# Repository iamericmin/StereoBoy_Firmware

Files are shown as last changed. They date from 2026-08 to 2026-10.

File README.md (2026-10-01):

# StereoBoy Firmware

Open-source firmware & hardware files for StereoBoy, the portable & modular stereo system!

The firmware project is organized as a Pico-SDK project that you can import directly into VSCode with Raspberry Pi's official Raspberry Pi Pico extension. You might need to git clone the [no-OS-FatFS-SD-SDIO-SPI-RPi-Pico repository](https://hackaday.io/project/205771-stereoboy).

The KiCad_files contains the full KiCad project should you want to produce your own PCBs. Make sure to order them in 1mm thickness, or else they won't fit into a GameBoy Pocket shell properly!!!

## What is this?

### FULL DISCLAIMER: I use AI-generated code for parts of this project! AI was used mainly for debugging and quick prototyping.



StereoBoy is a portable audio player I designed to be fit inside an original GameBoy Pocket shell. Read more about it here: [Hackaday Project Page](https://hackaday.io/project/205771-stereoboy)

**My main focus on the software side is providing a no-BS listening experience. For me, this implies a few things:**

 - Instant boot-up time
 - Intuitive UI that should ideally be easy enough to use without a manual
 - Simple, snappy UI that provides quick navigation between tracks, albums, artists, etc.
 - Easy to load music, with no software to manage file transfer
 - Plus the usual features such as an album art, equalizer, fast forward/rewind, etc.

So far, I've achieved sub-1s boot time that instantly provides a simple, iPod-like menu for albums, artists, and tracks as soon as you turn the device on, with a snappy interface that allows navigating through thousands of tracks with zero noticeable lag.

Music is loaded simply by dragging and dropping audio files on a micro-SD card, although a python script needs to be run to update the system cache with new track metadata. The script takes about 1.5 minutes to parse through a library of a little over 2000 songs. Thanks to the pre-generated metadata cache files, StereoBoy can instantly load fully sorted menus and crisp album artwork pretty much instantaneously.

Currently I have a very rudimentary equalizer going as well as buttery smooth fast forward/rewind. MP3s are the only supported file format, but I plan on adding FLAC support too.

**However, I also wanted to add some of my own personality to give the firmware some charm. Examples include:**

 - warp effect when pausing/resuming to simulate an analog tape reel. It's my favorite part of the entire project and never ever gets annoying.
 - Oscilloscope visualizer that displays super-high FPS waveforms of left and right channel audio
 - Audio plays at slightly lower speed and pitch on low battery to simulate a dying walkman (work in progress!)

## Let's get technical
### Here's a block diagram of the firmware architecture:

asdf

The firmware runs in a producer-consumer architecture, with Core 0 acting as the producer and Core 1 as the consumer. Core 0 mainly handles low-level peripherals and filesystem IO, such as opening/reading files and parsing track metadata. Core 1 mainly handles graphics and UI, reading data generated by Core 0 and rendering the appropriate visualizer/interface on the display and LEDs.

Both cores run their own superloop with very few interrupt-based routines. The firmware originally started out as a quick prototyping exercise for some core components, but eventually snowballed into what it is right now, and frankly I think it works alright for the task at hand. The current firmware architecture made it pretty easy to add features and modify existing components.

### Now here's a block diagram of the hardware architecture:



While the star of the show is an RP2350B microcontroller, it's actually a VS1063 audio codec that does the heavy lifting of all things related to audio. The RP2350's two cores handle user interface logic, graphics, and filesystem operations, while the codec crunches through audio data and provides the RP2350 with analog audio data, along with other useful tidbits of info such as playback timestamp or sampling frequency.

I2S output from the VS1063 is sent to a TLV320DAC3100, which is an integrated I2S DAC and headphone/speaker amp. It also controls the final output volume. The display is a 240x240 1.54" TFT LCD, and there is twin-bar VU meter for some extra flair. Currently it's only used as a visualizer but I plan on implementing more features into it, such as a battery level indicator. There is an 8KB FRAM chip to store last played track data plus some settings, and an 8-bit shift register takes care of all eight buttons to output to a single GPIO pin on the RP2350.

The power supply is a "double decker" structure where two PCBs are stacked on top of each other, with the top half containing the priority mux and 5V boost, while the bottom half contains the 1.8V and 3.3V buck regulators.

## The Future
### What do I have planned for the future?

 - 5-band graphic equalizer
 - Queue/play next
 - High-FPS FFT visualizer
 - Playlists
 - FLAC support
 - Last played song and timestamp available on boot-up
 - Settings to choose interface options and colors
 - Extras, like a timer/stopwatch/calendar
 - Games, like music quiz
 - More intuitive UI, some parts are a little clunky to use

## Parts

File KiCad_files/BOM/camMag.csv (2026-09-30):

Id | Designator | Footprint | Quantity | Designation | Supplier and ref
1 | J1 | GameBoy_GamePak_CGB-002_P1.50mm_Edge | 1 | GameBoy_GamePak_CGB-002
2 | C12,C16,C22,C18,C9,C14 | C_0402_1005Metric_Pad0.74x0.62mm_HandSolder | 6 | 10n
3 | C3,C15,C5,C13,C17,C4,C23 | C_0402_1005Metric_Pad0.74x0.62mm_HandSolder | 7 | 0.1u
4 | R5 | R_0402_1005Metric_Pad0.72x0.64mm_HandSolder | 1 | 1M
5 | J6 | microSD_External_Pin | 1 | microSD
6 | R4 | R_0402_1005Metric_Pad0.72x0.64mm_HandSolder | 1 | 1.69k
7 | FB1 | L_0603_1608Metric_Pad1.05x0.95mm_HandSolder | 1 | FerriteBead_Small
8 | C2,C1 | C_1206_3216Metric | 2 | 0.1uF
9 | D1 | LED_0603_1608Metric_Green | 1 | Green
10 | C21,C20 | C_0402_1005Metric_Pad0.74x0.62mm_HandSolder | 2 | 47p
11 | U2 | CP_32_12_ADI | 1 | ADV7180BCP32Z
12 | C19 | C_0402_1005Metric_Pad0.74x0.62mm_HandSolder | 1 | 82n
13 | U4 | SOT-23-5 | 1 | AP2112K-1.8
14 | C10,C11 | C_0603_1608Metric | 2 | 0.1u
15 | J2 | JST_ZH_B4B-ZR_1x04_P1.50mm_Vertical | 1 | Conn_01x04_Pin
16 | R6 | R_0603_1608Metric | 1 | 4k
17 | R3 | R_0402_1005Metric_Pad0.72x0.64mm_HandSolder | 1 | 36
18 | R1 | R_0603_1608Metric | 1 | 470
19 | Y1 | Crystal_SMD_Abracon_ABM8AIG-4Pin_3.2x2.5mm | 1 | ABM8-25.000MHZ-B2-T
20 | JP1 | R_0603_1608Metric | 1 | Jumper_2_Open
21 | R7 | R_0603_1608Metric | 1 | 470
22 | D2 | LED_0603_1608Metric | 1 | Blue
23 | C8 | C_0603_1608Metric_Pad1.08x0.95mm_HandSolder | 1 | 0.1u
24 | C6 | C_0603_1608Metric | 1 | 0.1uF
25 | R2 | R_0402_1005Metric_Pad0.72x0.64mm_HandSolder | 1 | 39
26 | U1 | SOIC-8_5.3x5.3mm_P1.27mm | 1 | W25Q16JVSS

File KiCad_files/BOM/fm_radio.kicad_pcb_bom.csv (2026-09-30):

Designator | Quantity | Value | Footprint | Package | MPN | DNP | Mount_Type | Description | PROD_ID | Voltage | Tolerance | Sim.Pins | MANUFACTURER | PART_REV | STANDARD
C1, C8 | 2 | 0.1uF | C_1206_3216Metric_Pad1.33x1.80mm_HandSolder |  |  |  | smt | Unpolarized capacitor | CAP-25565 | 16V | 10%
C11, C12 | 2 | 0.47 uF | C_0402_1005Metric_Pad0.74x0.62mm_HandSolder |  |  |  | smt | Unpolarized capacitor
C13 | 1 | 1 uF | C_0402_1005Metric_Pad0.74x0.62mm_HandSolder |  |  |  | smt | Unpolarized capacitor
C14, C17 | 2 | 100 pF | C_0402_1005Metric_Pad0.74x0.62mm_HandSolder |  |  |  | smt | Unpolarized capacitor
C15, C16 | 2 | 125 uF | C_0402_1005Metric_Pad0.74x0.62mm_HandSolder |  |  |  | smt | Unpolarized capacitor
C18 | 1 | 100pF | C_0402_1005Metric_Pad0.74x0.62mm_HandSolder |  |  |  | smt | Unpolarized capacitor
C2 | 1 | 4.7 uF | C_0402_1005Metric_Pad0.74x0.62mm_HandSolder |  |  |  | smt | Unpolarized capacitor
C3 | 1 | 1 nF | C_0402_1005Metric_Pad0.74x0.62mm_HandSolder |  |  |  | smt | Unpolarized capacitor
C4, C9 | 2 | 100 nF | C_0402_1005Metric_Pad0.74x0.62mm_HandSolder |  |  |  | smt | Unpolarized capacitor
C5 | 1 | 22 nF | C_0402_1005Metric_Pad0.74x0.62mm_HandSolder |  |  |  | smt | Unpolarized capacitor
C6 | 1 | 0.1uF | C_0402_1005Metric_Pad0.74x0.62mm_HandSolder |  |  |  | smt | Unpolarized capacitor | CAP-00810 | 25V | 20%
C7 | 1 | 0.1uF | C_0603_1608Metric |  |  |  | smt | Unpolarized capacitor | CAP-00810 | 25V | 20%
D1, D2, D3 | 3 | TPD1E01B04DPYR | DIO_TPD1E05U06DPYR |  |  |  | smt
D4 | 1 | LED | LED_0603_1608Metric_Pad1.05x0.95mm_HandSolder |  |  |  | smt | Light emitting diode |  |  |  | 1=K 2=A
FB1, FB2 | 2 | FerriteBead_Small | BEADC1608X95N |  |  |  | smt | Ferrite bead, small symbol
J1 | 1 | GameBoy_GamePak_CGB-002 | GameBoy_GamePak_CGB-002_P1.50mm_Edge |  |  |  | tht
J2 | 1 | SJ-43514 | SJ_43514 |  |  |  | tht |  |  |  |  |  | CUI INC | 1.04 | MANUFACTURER RECOMMENDATIONS
J6 | 1 | microSD | microSD_External_Pin |  |  |  | smt | Micro SD socket External Pin | CONN-16110
L1 | 1 | 270 nH | L_0402_1005Metric_Pad0.77x0.64mm_HandSolder |  |  |  | smt | Inductor
R1 | 1 | 1k | R_0603_1608Metric |  |  |  | smt | Resistor | RES-07869
R10, R4, R5, R6, R7 | 5 | 20k | R_0603_1608Metric |  |  |  | smt | Resistor | RES-07869
R11 | 1 | 600 | R_0603_1608Metric |  |  |  | smt | Resistor | RES-07869
R12, R13 | 2 | 2k | R_0603_1608Metric |  |  |  | smt | Resistor | RES-07869
R2, R3 | 2 | 4.7k | R_0603_1608Metric |  |  |  | smt | Resistor | RES-07869
R8, R9 | 2 | 100k | R_0603_1608Metric |  |  |  | smt | Resistor | RES-07869
U1 | 1 | W25Q16JVSS | SOIC-8_5.3x5.3mm_P1.27mm |  |  |  | smt | 16Mbit / 2MiB Serial Flash Memory, Standard/Dual/Quad SPI, 2.7-3.6V, SOIC-8 (208 mil)
U2 | 1 | SI4705-D60-GU | SOP64P600X175-24N |  |  |  | smt
U4 | 1 | LM4810 | TSSOP-8_3x3mm_P0.65mm |  |  |  | smt | Boomer Dual 105mW Headphone Amplifier with Active-High Shutdown Mode, VSSOP-8
Y2 | 1 | SIT1533AI-H4-DCC-32.768E | XTAL4_SiT1533_SIT |  |  |  | smt | SiTime Low Power Mems programmable oscillator, 1MHz to 110MHz, PQFN-4, 2.5x2.0mm (with NC pin)

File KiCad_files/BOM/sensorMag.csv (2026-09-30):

Id | Designator | Footprint | Quantity | Designation | Supplier and ref
1 | J1 | GameBoy_GamePak_CGB-002_P1.50mm_Edge | 1 | GameBoy_GamePak_CGB-002
2 | BT1 | BAT_BAT-HLD-012-SMT | 1 | BAT-HLD-012-SMT
3 | R4 | R_0603_1608Metric_Pad0.98x0.95mm_HandSolder | 1 | 1000
4 | J6 | microSD_External_Pin | 1 | microSD
5 | U3 | Bosch_LGA-8_2.5x2.5mm_P0.65mm_ClockwisePinNumbering | 1 | BME280
6 | R7 | R_0603_1608Metric | 1 | 4.7k
7 | C10 | C_0603_1608Metric_Pad1.08x0.95mm_HandSolder | 1 | 1u
8 | R3 | R_0603_1608Metric | 1 | 10k
9 | C4,C3,C5,C8 | C_0603_1608Metric | 4 | 100n
10 | C2,C1 | C_1206_3216Metric | 2 | 0.1uF
11 | D1 | LED_0603_1608Metric_Green | 1 | Green
12 | C11,C9 | C_0603_1608Metric_Pad1.08x0.95mm_HandSolder | 2 | 0.1u
13 | R5 | R_0603_1608Metric_Pad0.98x0.95mm_HandSolder | 1 | 4.7k
14 | R2,R6 | R_0603_1608Metric | 2 | 0
15 | U6 | OPTO-SMD_LITEON_LTR-381RGB-01 | 1 | ColorSensor
16 | R1 | R_0603_1608Metric | 1 | 470
17 | U4 | SOIC-14_L10.1-W5.0-P1.27-LS7.4-BL | 1 | RealTimeClock
18 | U2 | XDCR_LSM6DSO32TR | 1 | LSM6DSO32TR
19 | D2 | SOT-23 | 1 | BAT54C
20 | C6 | C_0603_1608Metric | 1 | 0.1uF
21 | U1 | SOIC-8_5.3x5.3mm_P1.27mm | 1 | W25Q16JVSS

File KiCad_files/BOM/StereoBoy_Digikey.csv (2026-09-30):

Index | Quantity | Part Number | Manufacturer Part Number | Description | Customer Reference | Available | Backorder | Unit Price | Extended Price USD
1 | 5 | 2648-SC1510-A4CT-ND | SC1510-A4 | RP2350B / 7" REEL - 500PCS |  | 5 | 0 | 1.00000 | 5.00
2 | 5 | 535-AMPLH7020S-6R8MTCT-ND | AMPLH7020S-6R8MT | FIXED IND 6.8UH 5.3A 64 MOHM SMD |  | 5 | 0 | 0.82000 | 4.10
3 | 5 | 516-4291-1-ND | ASMB-LTD2-0A333 | LED RGB DIFFUSED 4PLCC SMD |  | 5 | 0 | 0.58000 | 2.90
4 | 2 | 296-27216-1-ND | TLV320DAC3100IRHBR | IC DAC 24BIT 192K 32VQFN |  | 2 | 0 | 2.30000 | 4.60
5 | 1 | 4809-RK10J11R0A0LCT-ND | RK10J11R0A0L | THUMBWHEEL POT 10KOHM 0.03W TOP |  | 1 | 0 | 2.87000 | 2.87
6 | 1 | APX803S-31SA-7DICT-ND | APX803S-31SA-7 | IC SUPERVISOR 1 CHANNEL SOT23 |  | 1 | 0 | 0.24000 | 0.24
7 | 1 | BSS138CT-ND | BSS138 | MOSFET N-CH 50V 220MA SOT23-3 |  | 1 | 0 | 0.28000 | 0.28
8 | 1 | 497-11883-1-ND | USBLC6-4SC6Y | TVS DIODE 5.25VWM 17VC SOT23-6 |  | 1 | 0 | 0.32000 | 0.32
9 | 4 | 2073-USB4105-GF-A-120CT-ND | USB4105-GF-A-120 | CONN RCP USB2.0 TYP C 16P SMD RA |  | 4 | 0 | 0.78000 | 3.12
10 | 1 | DMG2301L-7DICT-ND | DMG2301L-7 | MOSFET P-CH 20V 3A SOT23 |  | 1 | 0 | 0.26000 | 0.26
11 | 1 | 490-9647-1-ND | PKMCS0909E4000-R1 | BUZZER PIEZO 9X9MM SMD |  | 1 | 0 | 0.92000 | 0.92
12 | 5 | 535-AOTA-B201610S3R3-101-TCT-ND | AOTA-B201610S3R3-101-T | FIXED IND 3.3UH 2.1A 140 MOHM |  | 5 | 0 | 0.21000 | 1.05
13 | 1 | FDN306PCT-ND | FDN306P | MOSFET P-CH 12V 2.6A SUPERSOT3 |  | 1 | 0 | 0.70000 | 0.70
14 | 2 | 296-23151-1-ND | SN74HC165DBR | IC SHIFT REGTR COMP 8BIT 16-SSOP |  | 2 | 0 | 0.44000 | 0.88
15 | 1 | 448-FM24C64B-GTRCT-ND | FM24C64B-GTR | IC FRAM 64KBIT I2C 1MHZ 8SOIC |  | 1 | 0 | 3.17000 | 3.17
16 | 10 | W25Q32JWSSIQ-ND | W25Q32JWSSIQ | IC FLASH 32MBIT SPI/QUAD 8SOIC |  | 10 | 0 | 1.02900 | 10.29
17 | 2 | 296-15240-1-ND | TPS61092RSAR | IC REG BOOST 5V 2A 16QFN |  | 2 | 0 | 2.71000 | 5.42
18 | 2 | 296-47360-1-ND | TLV62569DBVR | IC REG BUCK ADJ 2A SOT23-5 |  | 2 | 0 | 0.25000 | 0.50
19 | 10 | 535-AMELA3012S-2R2MTCT-ND | AMELA3012S-2R2MT | FIXED IND 2.2UH 3.3A 74 MOHM SMD |  | 10 | 0 | 0.77300 | 7.73
20 | 2 | 535-ABM8-272-T3CT-ND | ABM8-272-T3 | CRYSTAL 12.0000MHZ 10PF SMD |  | 2 | 0 | 0.54000 | 1.08
21 | 1 | 296-48721-1-ND | TPD1E01B04DPYR | TVS DIODE 3.6VWM 15VC 2X1SON |  | 1 | 0 | 0.39000 | 0.39
22 | 1 | 1473-1239-1-ND | SIT1533AI-H4-DCC-32.768E | MEMS OSC XO 32.7680KHZ LVCMOS |  | 1 | 0 | 1.33000 | 1.33
23 | 1 | 296-10846-1-ND | TPA6111A2DR | IC AMP CLASS AB STER 150MW 8SOIC |  | 1 | 0 | 1.13000 | 1.13
24 | 2 | CP-43514-ND | SJ-43514 | CONN JACK 4COND 3.5MM R/A |  | 2 | 0 | 1.20000 | 2.40
25 | 1 | 1N4148WTCT-ND | 1N4148WT | DIODE STANDARD 75V 200MA SOD523F |  | 1 | 0 | 0.11000 | 0.11
26 | 2 | 497-LSM6DSO32CT-ND | LSM6DSO32TR | INEMO INERTIAL MODULE: 3D ACCELE |  | 2 | 0 | 3.50000 | 7.00
27 | 2 | 828-1063-1-ND | BME280 | SENSOR PRESSURE HUMIDITY TEMP |  | 2 | 0 | 4.03000 | 8.06
28 | 2 | 568-5306-1-ND | PCF8523T/1,118 | IC RTC CLOCK/CALENDAR I2C 8SO |  | 2 | 0 | 1.35000 | 2.70
29 | 2 | AP2112K-1.8TRG1DICT-ND | AP2112K-1.8TRG1 | IC REG LINEAR 1.8V 600MA SOT-25 |  | 2 | 0 | 0.22000 | 0.44
30 | 2 | 535-9143-1-ND | ABM8-28.63636MHZ-B2-T | CRYSTAL 28.63636MHZ 18PF SMD |  | 2 | 0 | 0.43000 | 0.86
31 | 1 | 1528-2645-ND | 1681 | VS1053B MP3/WAV/OGG/MIDI PLAYER |  | 1 | 0 | 12.50000 | 12.50
32 | 10 | 493-3821-1-ND | RSL0J221MCN1GB | CAP ALUM POLY 220UF 20% 6.3V SMD |  | 10 | 0 | 0.73300 | 7.33
33 | 5 | 478-KC2016Z12.2880C15XXKCT-ND | KC2016Z12.2880C15XXK | CLOCK OSCILLATOR,2.0X1.6X0.8MM S |  | 5 | 0 | 1.27000 | 6.35
34 | 2 | 2223-MSD-4-ACT-ND | MSD-4-A | CONN MICROSD CARD R/A SMD |  | 2 | 0 | 0.36000 | 0.72
35 | 1 | 296-TPS2116DRLRCT-ND | TPS2116DRLR | 1.6-V TO 5.5-V, 40-M, 2.5-A, LOW |  | 1 | 0 | 0.90000 | 0.90

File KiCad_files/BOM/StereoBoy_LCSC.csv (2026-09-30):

Index | LCSC# | MPN | Manufacturer | Package | Customer # | Description | RoHS | Quantity | MOQ | Multiple | Unit Price($) | Extended Price($) | Product Link
1 | C179677 | TLV320DAC3100IRHBR | TI | HVQFN-32-EP(5x5) |  | 2.7V~5.5V Class D HVQFN-32-EP(5x5) ADCs/DACs - Special Purpose RoHS | yes | 3 | 1 | 1 | 1.5544 | 4.66 | https://www.lcsc.com/product-detail/C179677.html
2 | C9829 | FM24CL64B-GTR | Infineon/CYPRESS | SOIC-8-150mil |  | 64Kbit 2.7V~3.65V 1MHz I2C SOIC-8-150mil Memory (ICs) RoHS | yes | 4 | 1 | 1 | 1.0979 | 4.39 | https://www.lcsc.com/product-detail/C9829.html
3 | C3235557 | TPS2116DRLR | TI | SOT-583 |  | 2 Channel 2.5A SOT-583 | yes | 4 | 1 | 1 | 0.4034 | 1.61 | https://www.lcsc.com/product-detail/C3235557.html
4 | C141836 | TLV62569DBVR | TI | SOT-23-5 |  | 1.5MHz Buck Adjustable 600mV~5.5V 2A SOT-23-5 Voltage Regulators - DC DC Switching Regulators RoHS | yes | 10 | 10 | 10 | 0.0633 | 0.63 | https://www.lcsc.com/product-detail/C141836.html
5 | C15999 | USBLC6-2P6 | ST | SOT-666-6 |  | 17VC Clamp 5A@8/20us Ipp ESD DIODE SOT-666-6 | yes | 10 | 5 | 5 | 0.1790 | 1.79 | https://www.lcsc.com/product-detail/C15999.html
6 | C20182909 | SJ-43514 | CUI | - |  | Audio Connectors RoHS | yes | 3 | 1 | 1 | 1.2924 | 3.88 | https://www.lcsc.com/product-detail/C20182909.html
7 | C5184243 | USB4105-GF-A-120 | Global Connector Technology | SMD |  | USB-C (USB TYPE-C) Receptacle Connector 16 Position Surface Mount | yes | 2 | 1 | 1 | 0.9256 | 1.85 | https://www.lcsc.com/product-detail/C5184243.html
8 | C115407 | W25Q16JVSNIQ | Winbond | SOIC-8 |  | 2.7V~3.6V 16Mbit 133MHz SPI SOIC-8 Memory (ICs) RoHS | yes | 2 | 1 | 1 | 1.5671 | 3.13 | https://www.lcsc.com/product-detail/C115407.html
9 | C470766 | RK10J11R0A0H | ALPSALPINE | SMD |  | ±30% 30mW 10kΩ SMD Trimmer Potentiometers RoHS | yes | 4 | 1 | 1 | 0.6546 | 2.62 | https://www.lcsc.com/product-detail/C470766.html
10 | C910763 | PKMCS0909E4000-R1 | muRata | - |  | Buzzers Passive (Externally Driven) Piezoelectric 12.5V 4kHz 65dB | yes | 4 | 1 | 1 | 0.7740 | 3.10 | https://www.lcsc.com/product-detail/C910763.html
11 | C154510 | FDN306P | onsemi | SOT-23 |  | P-Channel 12V 2.6A 0.5W Surface Mount SOT-23 | yes | 5 | 5 | 5 | 0.2449 | 1.22 | https://www.lcsc.com/product-detail/C154510.html
12 | C6466184 | APX803L-35SA-7 | DIODES | SOT-23-3 |  | 20ms Active Low 900mV~5.5V 1 SOT-23-3 Supervisors RoHS | yes | 5 | 5 | 5 | 0.1602 | 0.80 | https://www.lcsc.com/product-detail/C6466184.html
13 | C82045 | BSS138LT1G | onsemi | SOT-23 |  | N-Channel 50V 200mA 225mW Surface Mount SOT-23 | yes | 10 | 10 | 10 | 0.0407 | 0.41 | https://www.lcsc.com/product-detail/C82045.html
14 | C507236 | SN74HC165DBR | TI | SSOP-16-208mil |  | 2V~6V 4mA 26ns@6V,50pF Parallel or Serial to Serial SSOP-16-208mil Shift Registers RoHS | yes | 3 | 1 | 1 | 0.4240 | 1.27 | https://www.lcsc.com/product-detail/C507236.html
15 | C102619 | DMG2301L-7 | DIODES | SOT-23 |  | P-Channel 20V 3A 1.5W Surface Mount SOT-23 | yes | 10 | 10 | 10 | 0.0725 | 0.73 | https://www.lcsc.com/product-detail/C102619.html
16 | C486306 | VS1063A-L | VLSI | LQFP-48(7x7) |  | 48kHz LQFP-48(7x7) Audio Special Purpose RoHS | yes | 4 | 1 | 1 | 9.4263 | 37.71 | https://www.lcsc.com/product-detail/C486306.html
17 | C20625731 | ABM8-272-T3 | ABRACON | SMD3225-4P |  | ±30ppm 10pF ±30ppm SMD3225-4P Crystals RoHS | yes | 5 | 5 | 5 | 0.2923 | 1.46 | https://www.lcsc.com/product-detail/C20625731.html
18 | C779389 | TPD1E01B04DPYR | TI | X1-SON-2(0.6x1) |  | 15VC Clamp 2.5A@8/20us Ipp ESD DIODE X1-SON-2(0.6x1) | yes | 20 | 10 | 10 | 0.0591 | 1.18 | https://www.lcsc.com/product-detail/C779389.html
19 | C367058 | SIT1533AI-H4-DCC-32.768E | SiTime | SMD2012-4P |  | LVCMOS Programmable Oscillator 32.768kHz 1.5V~3.63V SMD2012-4P | yes | 4 | 1 | 1 | 1.0084 | 4.03 | https://www.lcsc.com/product-detail/C367058.html
20 | C497472 | TPA6111A2DR | TI | SOIC-8 |  | 2-Channel SOIC-8 Audio Amplifiers RoHS | yes | 4 | 1 | 1 | 0.5808 | 2.32 | https://www.lcsc.com/product-detail/C497472.html
21 | C92489 | BME280 | Bosch | LGA-8(2.5x2.5) |  | ±3%RH -40℃~+85℃ 0%RH~100%RH LGA-8(2.5x2.5) Humidity, Moisture Sensors RoHS | yes | 4 | 1 | 1 | 5.7962 | 23.18 | https://www.lcsc.com/product-detail/C92489.html
22 | C2651516 | PCF8523T/1,118 | NXP | SO-8 |  | Built-in Yes SO-8 Real Time Clocks RoHS | yes | 5 | 5 | 5 | 1.1599 | 5.80 | https://www.lcsc.com/product-detail/C2651516.html
23 | C14308 | BAT54CLT1G | onsemi | SOT-23 |  | Diode Array 1 Pair Common Cathode 30V 200mA Surface Mount SOT-23 | yes | 20 | 20 | 20 | 0.0280 | 0.56 | https://www.lcsc.com/product-detail/C14308.html
24 | C2878944 | TPS61092RSAR | TI | QFN-16-EP(4x4) |  | 600kHz Boost Fixed 5V QFN-16-EP(4x4) Voltage Regulators - DC DC Switching Regulators RoHS | yes | 3 | 1 | 1 | 2.5409 | 7.62 | https://www.lcsc.com/product-detail/C2878944.html
25 | C107335 | MPZ1608S601ATA00 | TDK | 0603 |  | 600Ω@100MHz 1 Line Ferrite Bead 0603 1A 150mΩ | yes | 20 | 10 | 10 | 0.0123 | 0.25 | https://www.lcsc.com/product-detail/C107335.html
26 | C94034 | GRM31CR61A476ME15L | muRata | 1206 |  | 47uF ±20% 10V Ceramic Capacitor X5R 1206 | yes | 20 | 10 | 10 | 0.0677 | 1.35 | https://www.lcsc.com/product-detail/C94034.html
27 | C15008 | CL31A107MQHNNNE | Samsung Electro-Mechanics | 1206 |  | 100uF ±20% 6.3V Ceramic Capacitor X5R 1206 | yes | 30 | 10 | 10 | 0.0610 | 1.83 | https://www.lcsc.com/product-detail/C15008.html
28 | C98192 | CL21A475KBQNNNE | Samsung Electro-Mechanics | 0805 |  | 4.7uF ±10% 50V Ceramic Capacitor X5R 0805 | yes | 20 | 10 | 10 | 0.0205 | 0.41 | https://www.lcsc.com/product-detail/C98192.html
29 | C7226 | TAJD337K010RNJ | Kyocera AVX | CASE-D-7343-31(mm) |  | 330uF ±10% 10V Tantalum Capacitors 900mΩ@100kHz CASE-D-7343 | yes | 10 | 1 | 1 | 0.5494 | 5.49 | https://www.lcsc.com/product-detail/C7226.html
30 | C440152 | GJM1555C1H150GB01D | muRata | 0402 |  | 15pF ±2% 50V Ceramic Capacitor C0G 0402 | yes | 20 | 20 | 20 | 0.0258 | 0.52 | https://www.lcsc.com/product-detail/C440152.html
31 | C161520 | GRM1555C1H100FA01D | muRata | 0402 |  | 10pF ±1% 50V Ceramic Capacitor C0G 0402 | yes | 100 | 100 | 100 | 0.0081 | 0.81 | https://www.lcsc.com/product-detail/C161520.html
32 | C137880 | RC0402JR-0733RL | YAGEO | 0402 |  | 62.5mW 33Ω 50V Thick Film Resistor ±100ppm/℃ ±5% 0402 Chip Resistor - Surface Mount RoHS | yes | 100 | 100 | 100 | 0.0007 | 0.07 | https://www.lcsc.com/product-detail/C137880.html
33 | C519995 | CC0805BRNPO9BN6R8 | YAGEO | 0805 |  | 6.8pF 50V Ceramic Capacitor NP0 0805 | yes | 50 | 50 | 50 | 0.0196 | 0.98 | https://www.lcsc.com/product-detail/C519995.html
34 | C160403 | SM03B-SRSS-TB(LF)(SN) | JST | SMD,P=1mm,Surface Mount,Right Angle |  | Connector Header 3 position 1mm Pitch 1A Surface Mount, Right Angle -25℃~+85℃ | yes | 5 | 5 | 5 | 0.1734 | 0.87 | https://www.lcsc.com/product-detail/C160403.html
35 | C20613191 | TF-01A-ZYD9AH1.85 | XYECONN | SMD |  | Micro SD card (TF card) Surface Mount | yes | 20 | 5 | 5 | 0.0705 | 1.41 | https://www.lcsc.com/product-detail/C20613191.html
36 | C92361 | CL05A474KA5NNNC | Samsung Electro-Mechanics | 0402 |  | 470nF ±10% 25V Ceramic Capacitor X5R 0402 | yes | 20 | 10 | 10 | 0.0128 | 0.26 | https://www.lcsc.com/product-detail/C92361.html
37 | C24497 | CL31B104KBCNNNC | Samsung Electro-Mechanics | 1206 |  | 100nF ±10% 50V Ceramic Capacitor X7R 1206 | yes | 40 | 20 | 20 | 0.0155 | 0.62 | https://www.lcsc.com/product-detail/C24497.html
38 | C106205 | CC0402KRX7R9BB102 | YAGEO | 0402 |  | 1nF ±10% 50V Ceramic Capacitor X7R 0402 | yes | 100 | 100 | 100 | 0.0011 | 0.11 | https://www.lcsc.com/product-detail/C106205.html
39 | C77177 | GRM1555C1H101JA01D | muRata | 0402 |  | 100pF ±5% 50V Ceramic Capacitor C0G 0402 | yes | 100 | 100 | 100 | 0.0032 | 0.32 | https://www.lcsc.com/product-detail/C77177.html
40 | C107017 | CC0402KRX7R7BB223 | YAGEO | 0402 |  | 22nF ±10% 16V Ceramic Capacitor X7R 0402 | yes | 100 | 100 | 100 | 0.0020 | 0.20 | https://www.lcsc.com/product-detail/C107017.html
41 | C703734 | LQW15CAR27J00D | muRata | 0402 |  | 480mA 270nH 380mΩ Unshielded Inductor ±5% 0402 Fixed Inductors RoHS | yes | 5 | 5 | 5 | 0.1150 | 0.58 | https://www.lcsc.com/product-detail/C703734.html
42 | C138033 | RC0402FR-071ML | YAGEO | 0402 |  | 62.5mW 1MΩ 50V Thick Film Resistor ±100ppm/℃ ±1% 0402 Chip Resistor - Surface Mount RoHS | yes | 100 | 100 | 100 | 0.0008 | 0.08 | https://www.lcsc.com/product-detail/C138033.html
43 | C14675 | RC0603FR-07100KL | YAGEO | 0603 |  | 100mW 100kΩ 75V Thick Film Resistor ±100ppm/℃ ±1% 0603 Chip Resistor - Surface Mount RoHS | yes | 100 | 100 | 100 | 0.0013 | 0.13 | https://www.lcsc.com/product-detail/C14675.html
44 | C105574 | RC0603FR-07200KL | YAGEO | 0603 |  | 100mW 200kΩ 75V Thick Film Resistor ±100ppm/℃ ±1% 0603 Chip Resistor - Surface Mount RoHS | yes | 100 | 100 | 100 | 0.0014 | 0.14 | https://www.lcsc.com/product-detail/C105574.html
45 | C273765 | RC0603FR-07453KL | YAGEO | 0603 |  | 453kΩ 100mW 75V Thick Film Resistor ±100ppm/℃ ±1% 0603 Chip Resistor - Surface Mount RoHS | yes | 100 | 100 | 100 | 0.0015 | 0.15 | https://www.lcsc.com/product-detail/C273765.html
46 | C7280951 | DY-S321610UGC-T2-3T-03 | TONYU | 1206 |  | Green 535nm LED Indication - Discrete 2.35V~2.75V 1206 | yes | 50 | 50 | 50 | 0.0159 | 0.80 | https://www.lcsc.com/product-detail/C7280951.html
47 | C163467 | RC0402FR-07390KL | YAGEO | 0402 |  | 62.5mW 390kΩ 50V Thick Film Resistor ±100ppm/℃ ±1% 0402 Chip Resistor - Surface Mount RoHS | yes | 100 | 100 | 100 | 0.0009 | 0.09 | https://www.lcsc.com/product-detail/C163467.html
48 | C482199 | CRCW0402510KFKED | VISHAY | 0402 |  | 510kΩ 62.5mW 50V Thick Film Resistor ±1% ±100ppm/℃ 0402 Chip Resistor - Surface Mount RoHS | yes | 100 | 100 | 100 | 0.0041 | 0.41 | https://www.lcsc.com/product-detail/C482199.html
49 | C596899 | ABM8-25.000MHZ-B2-T | ABRACON | SMD3225-4P |  | Crystal 25MHz ±20ppm 18pF 50Ω SMD3225-4P | yes | 3 | 1 | 1 | 0.5218 | 1.57 | https://www.lcsc.com/product-detail/C596899.html
50 | C185420 | RC0402FR-0739RL | YAGEO | 0402 |  | 62.5mW 39Ω 50V Thick Film Resistor ±100ppm/℃ ±1% 0402 Chip Resistor - Surface Mount RoHS | yes | 100 | 100 | 100 | 0.0008 | 0.08 | https://www.lcsc.com/product-detail/C185420.html
51 | C2871753 | LM4810MMX/NOPB | TI | VSSOP-8 |  | 2-Channel VSSOP-8 Audio Amplifiers RoHS | yes | 5 | 1 | 1 | 0.5255 | 2.63 | https://www.lcsc.com/product-detail/C2871753.html
52 | C157997 | B4B-ZR(LF)(SN) | JST | Through Hole,P=1.5mm |  | Connector Header 4 position 1.5mm Pitch 1A Through Hole -25℃~+85℃ | yes | 5 | 5 | 5 | 0.1168 | 0.58 | https://www.lcsc.com/product-detail/C157997.html
53 | C5126050 | FRC0402F1691TS | FOJAN | 0402 |  | 1.69kΩ ±1% 62.5mW 0402 Thick Film Resistor | yes | 100 | 100 | 100 | 0.0006 | 0.06 | https://www.lcsc.com/product-detail/C5126050.html
54 | C15195 | CL05B103KB5NNNC | Samsung Electro-Mechanics | 0402 |  | 10nF ±10% 50V Ceramic Capacitor X7R 0402 | yes | 100 | 100 | 100 | 0.0015 | 0.15 | https://www.lcsc.com/product-detail/C15195.html
55 | C314277 | 0402B823K100CT | Walsin | 0402 |  | 82nF ±10% 10V Ceramic Capacitor X7R 0402 | yes | 50 | 50 | 50 | 0.0009 | 0.05 | https://www.lcsc.com/product-detail/C314277.html
56 | C60137 | CC0402JRNPO9BN470 | YAGEO | 0402 |  | 47pF ±5% 50V Ceramic Capacitor NP0 0402 | yes | 100 | 100 | 100 | 0.0012 | 0.12 | https://www.lcsc.com/product-detail/C60137.html
57 | C2998152 | FRC0402F36R0TS | FOJAN | 0402 |  | 36Ω ±1% 62.5mW 0402 Thick Film Resistor | yes | 100 | 100 | 100 | 0.0005 | 0.05 | https://www.lcsc.com/product-detail/C2998152.html
58 | C114877 | RC0402FR-07470RL | YAGEO | 0402 |  | 62.5mW 470Ω 50V Thick Film Resistor ±100ppm/℃ ±1% 0402 Chip Resistor - Surface Mount RoHS | yes | 100 | 100 | 100 | 0.0008 | 0.08 | https://www.lcsc.com/product-detail/C114877.html
59 | C23179 | 0603WAF4700T5E | UNI-ROYAL | 0603 |  | 470Ω ±1% 100mW 0603 Thick Film Resistor | yes | 100 | 100 | 100 | 0.0015 | 0.15 | https://www.lcsc.com/product-detail/C23179.html
60 | C2907024 | FRC0603F3901TS | FOJAN | 0603 |  | 3.9kΩ ±1% 100mW 0603 Thick Film Resistor | yes | 100 | 100 | 100 | 0.0012 | 0.12 | https://www.lcsc.com/product-detail/C2907024.html
61 | C5189234 | BAT-HLD-012-SMT | TE Connectivity | SMD |  | SMD Battery Holders, Clips, Contacts RoHS | yes | 3 | 1 | 1 | 0.9498 | 2.85 | https://www.lcsc.com/product-detail/C5189234.html
62 | C2944020 | LTR-381RGB-01 | LITEON | SMD-6P,2x2mm |  | I2C 1.7V~3.6V SMD-6P,2x2mm Ambient Light, IR, UV Sensors | - | 2 | 1 | 1 | 0.9685 | 1.94 | https://www.lcsc.com/product-detail/C2944020.html
63 | C37704 | BAT54C,215 | Nexperia | SOT-23 |  | Diode Array 1 Pair Common Cathode 30V 200mA Surface Mount SOT-23 | yes | 10 | 10 | 10 | 0.0523 | 0.52 | https://www.lcsc.com/product-detail/C37704.html
64 | C138021 | RC0402FR-0727RL | YAGEO | 0402 |  | 27Ω ±1% 62.5mW 0402 Thick Film Resistor | yes | 100 | 100 | 100 | 0.0009 | 0.09 | https://www.lcsc.com/product-detail/C138021.html

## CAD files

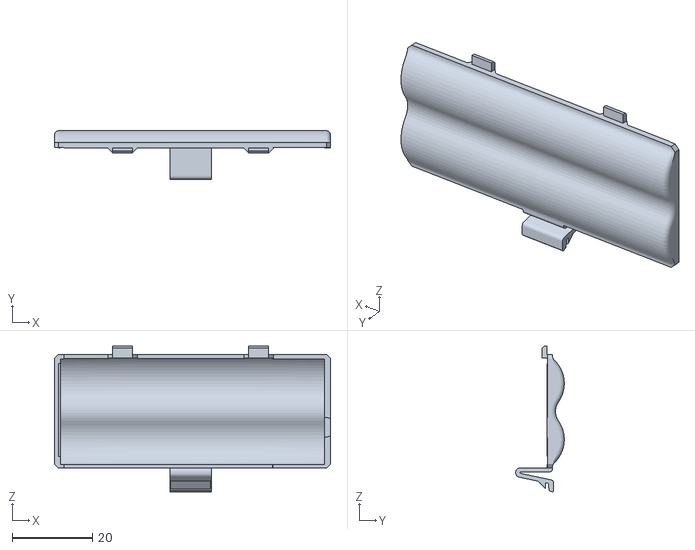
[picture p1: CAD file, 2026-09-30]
KiCad_files/stereoBoy_3D/AA Battery Cover V4.stl
68.9 x 12.1 x 36.4

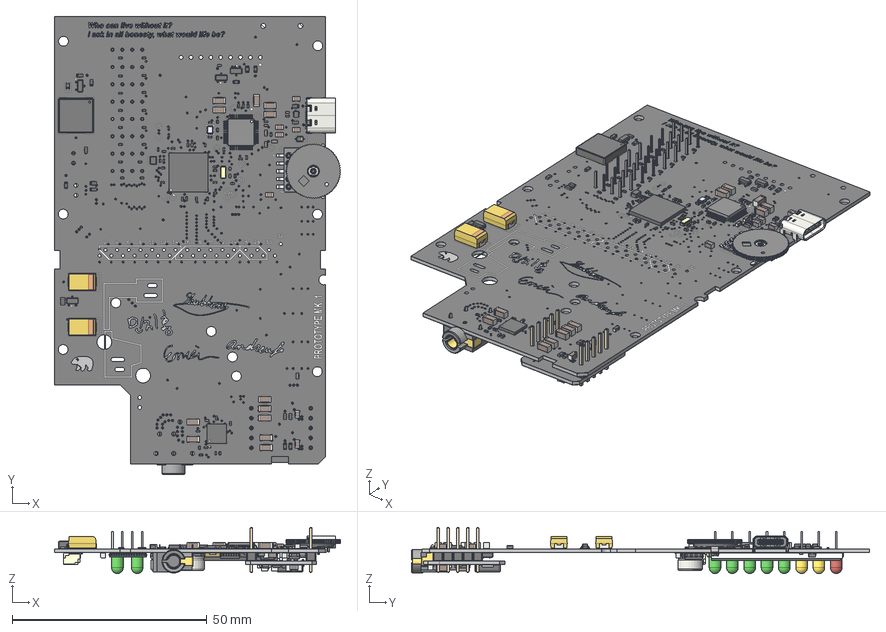
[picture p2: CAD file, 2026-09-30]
KiCad_files/stereoBoy_MGB.step
73.5 x 117.6 x 11.8 mm
R_0603_1608Metric x 26
C_1206_3216Metric x 16
R_0402_1005Metric x 34
C_0805_2012Metric x 15
C_0402_1005Metric x 42
CP_EIA-7343-31_Kemet-D x 2
C_0603_1608Metric x 8
L_0603_1608Metric x 4
Crystal_SMD_2.0x1.6mm
USB_C_Receptacle_GCT_USB4105-xx-A_16P_TopMnt_Horizontal
D_0603_1608Metric
D_SOD-323
SOT-23 x 4
SOT-666
QFN-80-1EP_10x10mm_P0.4mm_EP3.4x3.4mm
QFN-32-1EP_5x5mm_P0.5mm_EP3.45x3.45mm
L_Cenker_CKCS201610
VS1053b
R_0805_2012Metric
Crystal_SMD_3.2x1.5mm
Buzzer_Murata_PKMCS0909E
RK10J11R0A0L
LED_D3.0mm_Green x 10
CP_Elec_6.3x4.5 x 2
SJ-43514
L_APV_ANR3012 x 2
LED_D3.0mm_Yellow x 4
SOIC-8_3.9x4.9mm_P1.27mm
LED_D3.0mm x 2
SOT-23-5 x 2
LCD 1.54 inch 240x240 ST7789
tactile_switch_3.5x2.9_4F x 46
TSSOP-28_4.4x9.7mm_P0.65mm
JST_SMD_1.0mm-3
PinHeader_1x05_P2.54mm_Vertical x 2
SOT-583-8
Texas_RSA_VQFN-16-1EP_4x4mm_P0.65mm_EP2.7x2.7mm
L_APV_APH0620
L_0805_2012Metric
LED_1206_3216Metric_Castellated_Green
stereoBoy_MGB_silkscreen x 2
stereoBoy_MGB_soldermask x 2
stereoBoy_MGB_PCB x 2
SSOP-16_4.4x5.2mm_P0.65mm
CREE_LED_2mm_x_2mm_Common_Anode

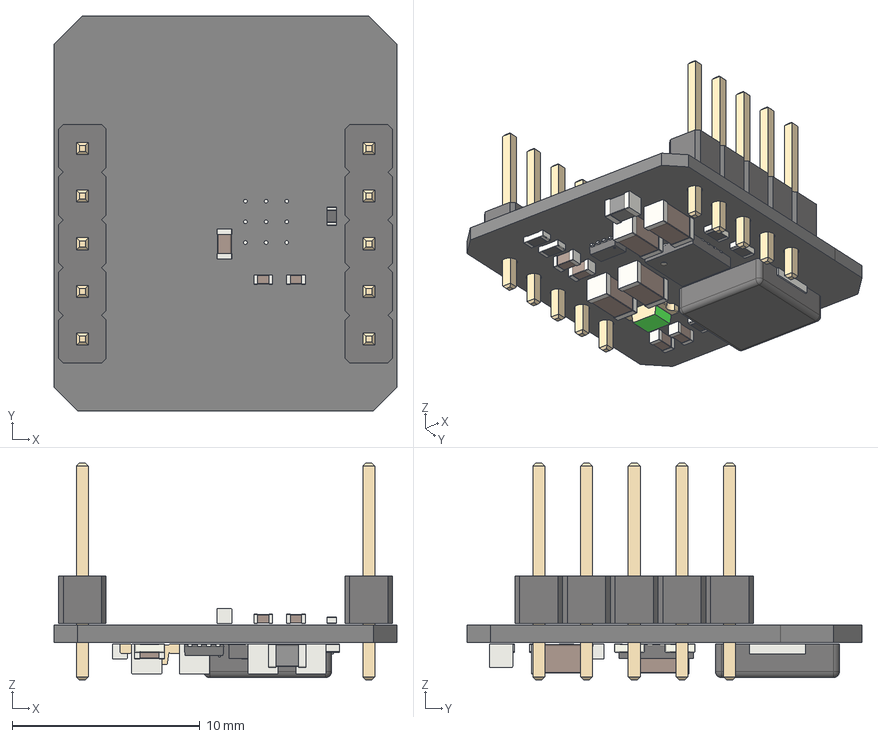
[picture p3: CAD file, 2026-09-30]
KiCad_files/PSU_module.step
18.2 x 21.0 x 11.5 mm
R_0402_1005Metric
C_0402_1005Metric x 2
PinHeader_1x05_P2.54mm_Vertical x 2
C_0603_1608Metric x 5
SOT-583-8
R_0603_1608Metric x 5
C_1206_3216Metric x 4
Texas_RSA_VQFN-16-1EP_4x4mm_P0.65mm_EP2.7x2.7mm
L_APV_APH0620
L_0805_2012Metric
LED_1206_3216Metric_Castellated_Green
stereoBoy_MGB_PCB

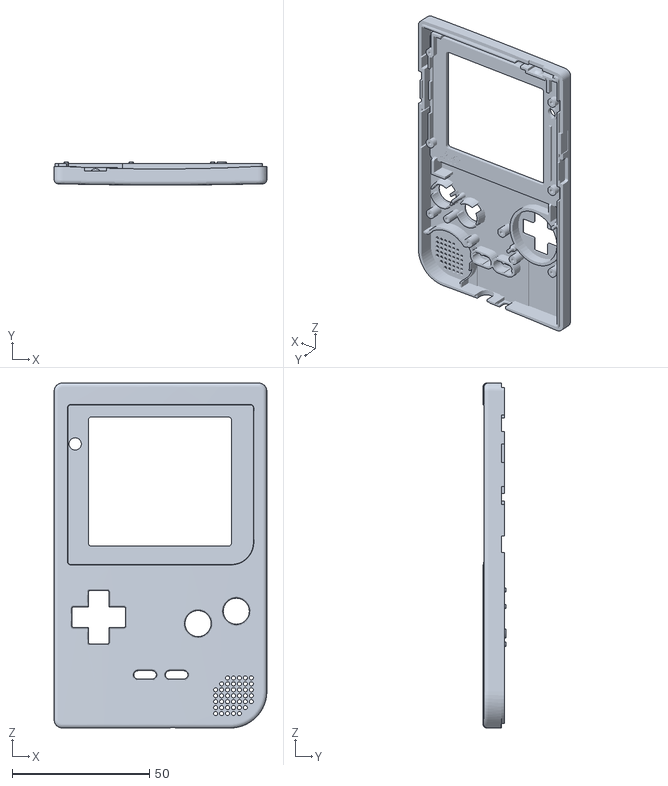
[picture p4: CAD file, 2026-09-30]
KiCad_files/stereoBoy_3D/OEM CURVE FRONT Revised.stl
77.5 x 8.43 x 125.7

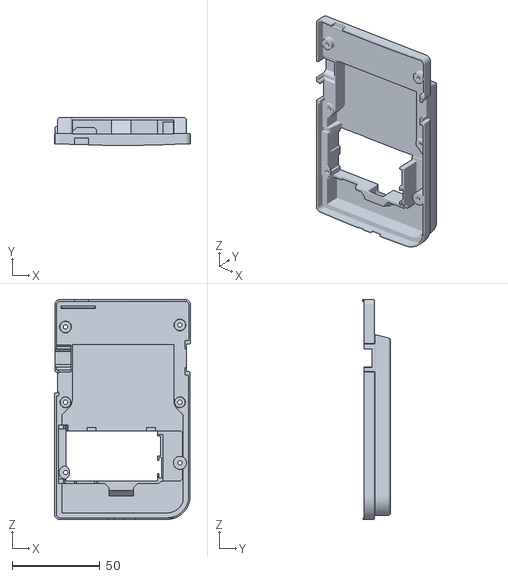
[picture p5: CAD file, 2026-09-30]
KiCad_files/stereoBoy_3D/AA Battery Pocket Rear V7.stl
77.7 x 15.9 x 125.7

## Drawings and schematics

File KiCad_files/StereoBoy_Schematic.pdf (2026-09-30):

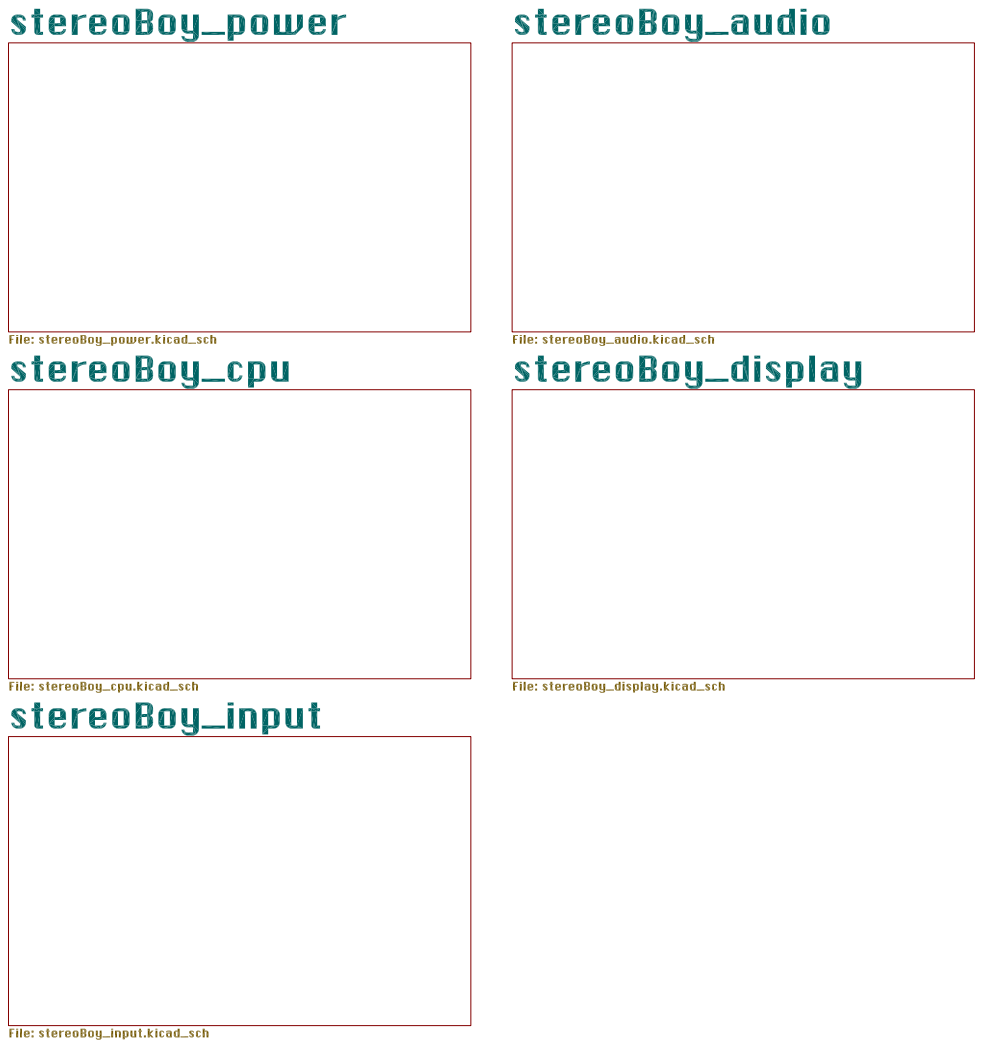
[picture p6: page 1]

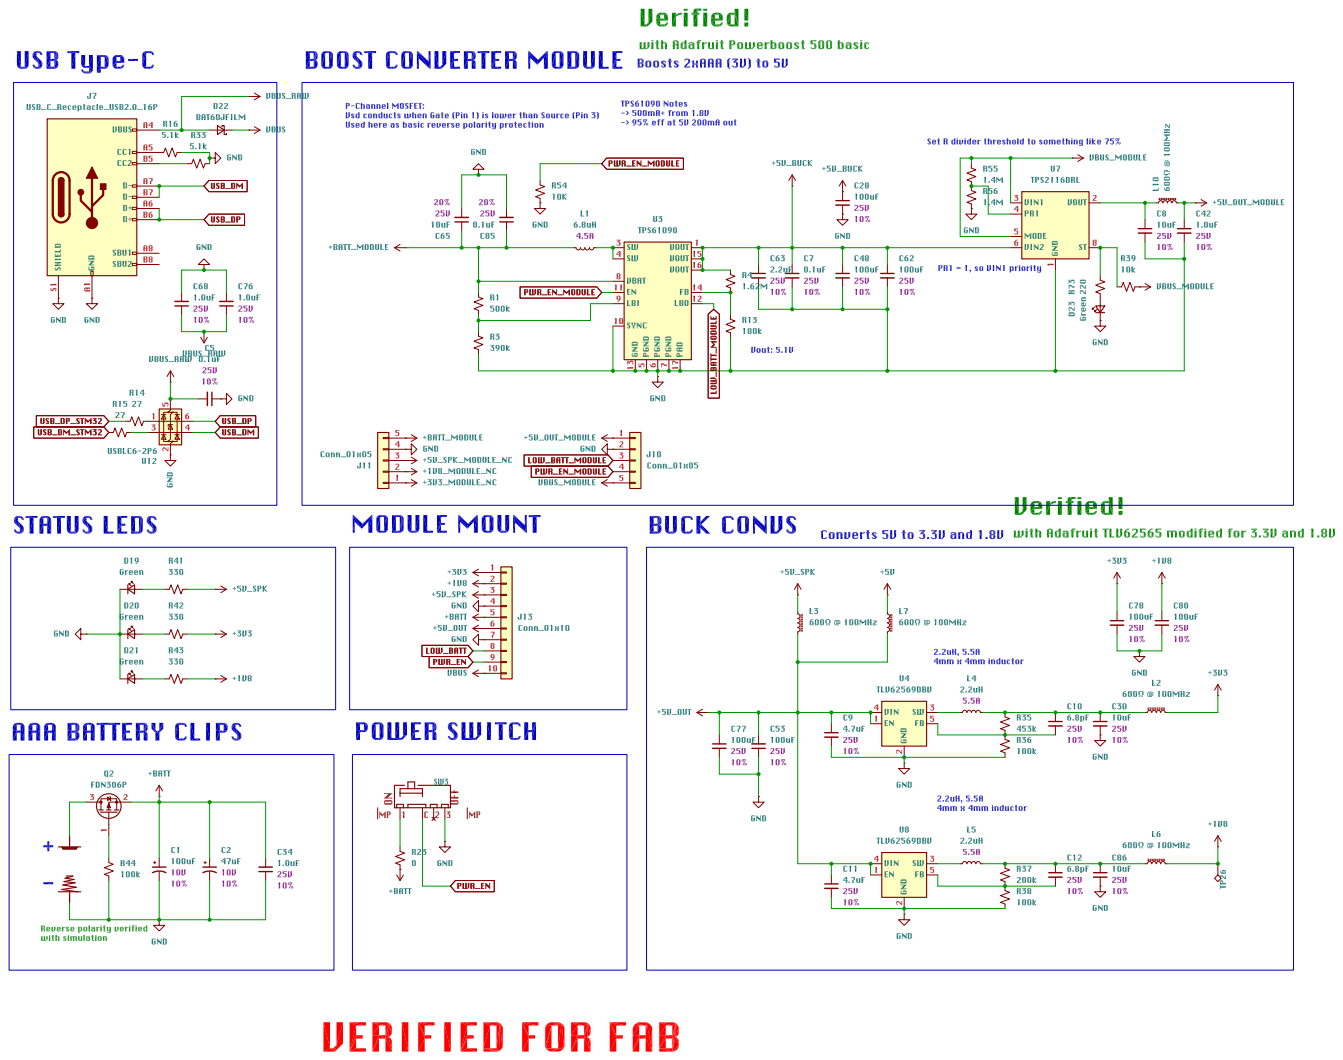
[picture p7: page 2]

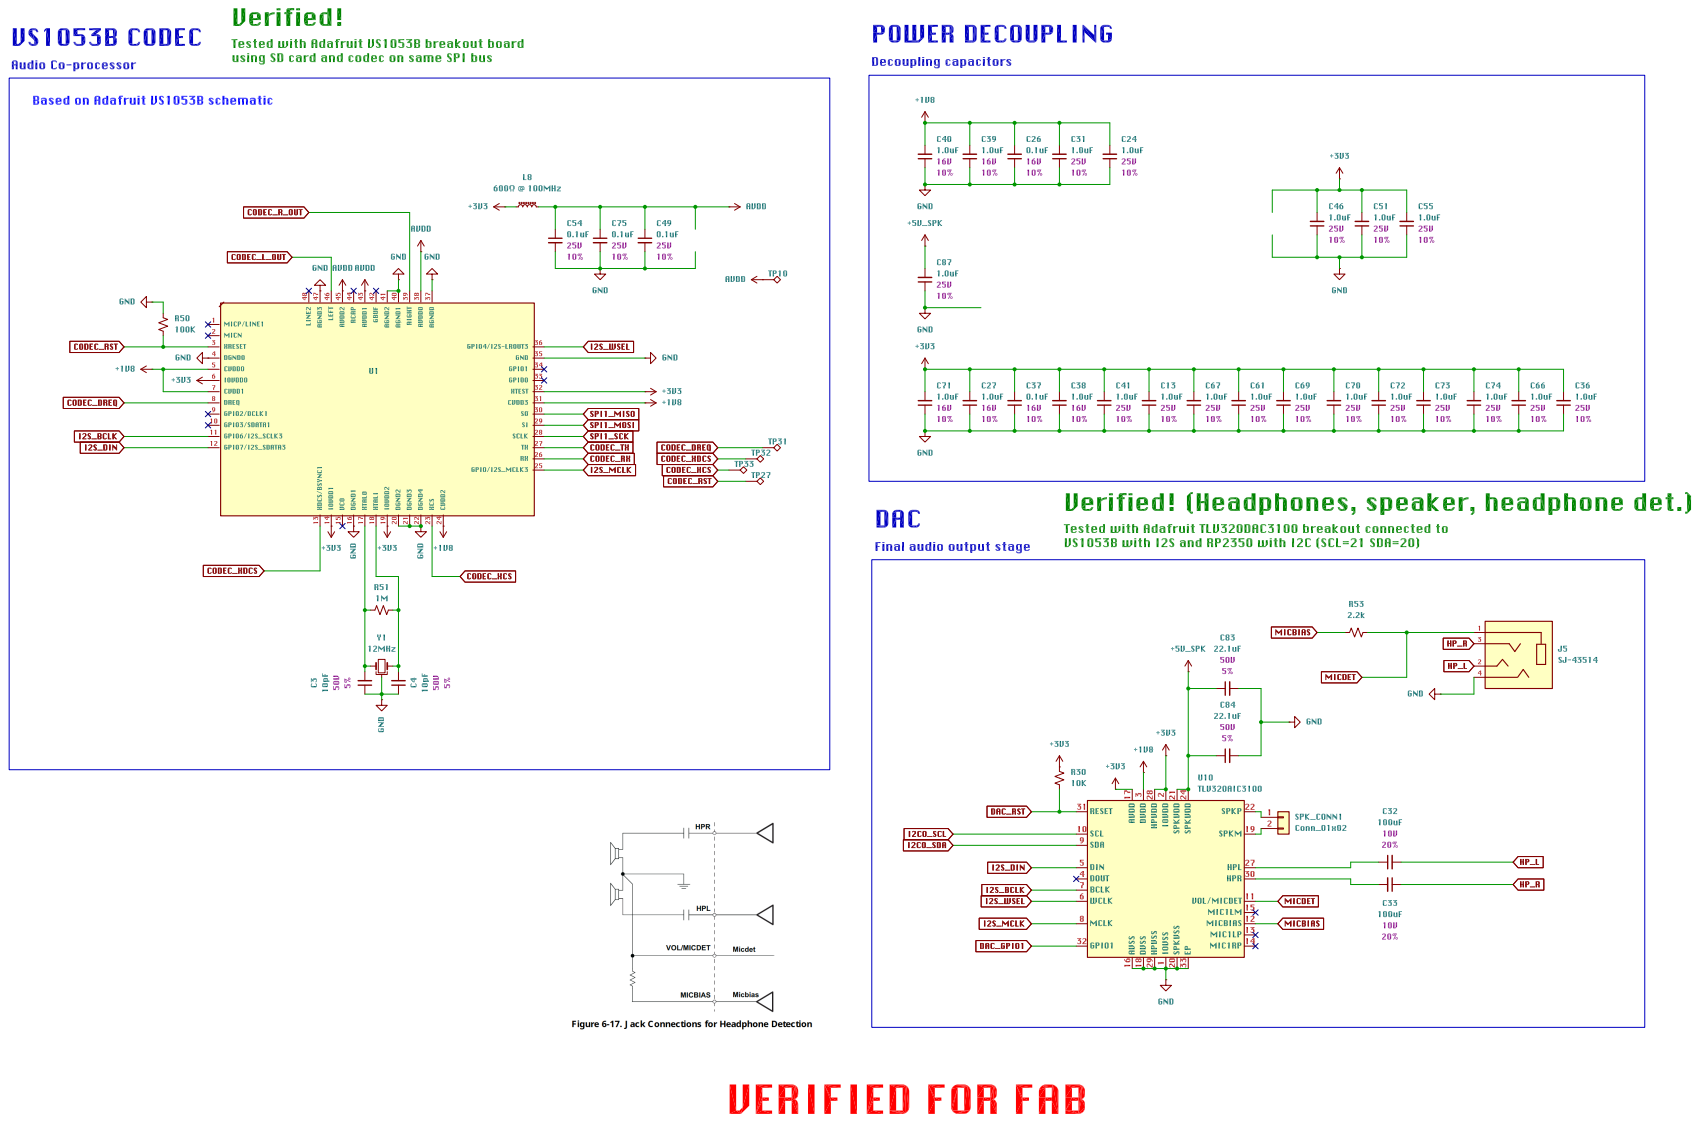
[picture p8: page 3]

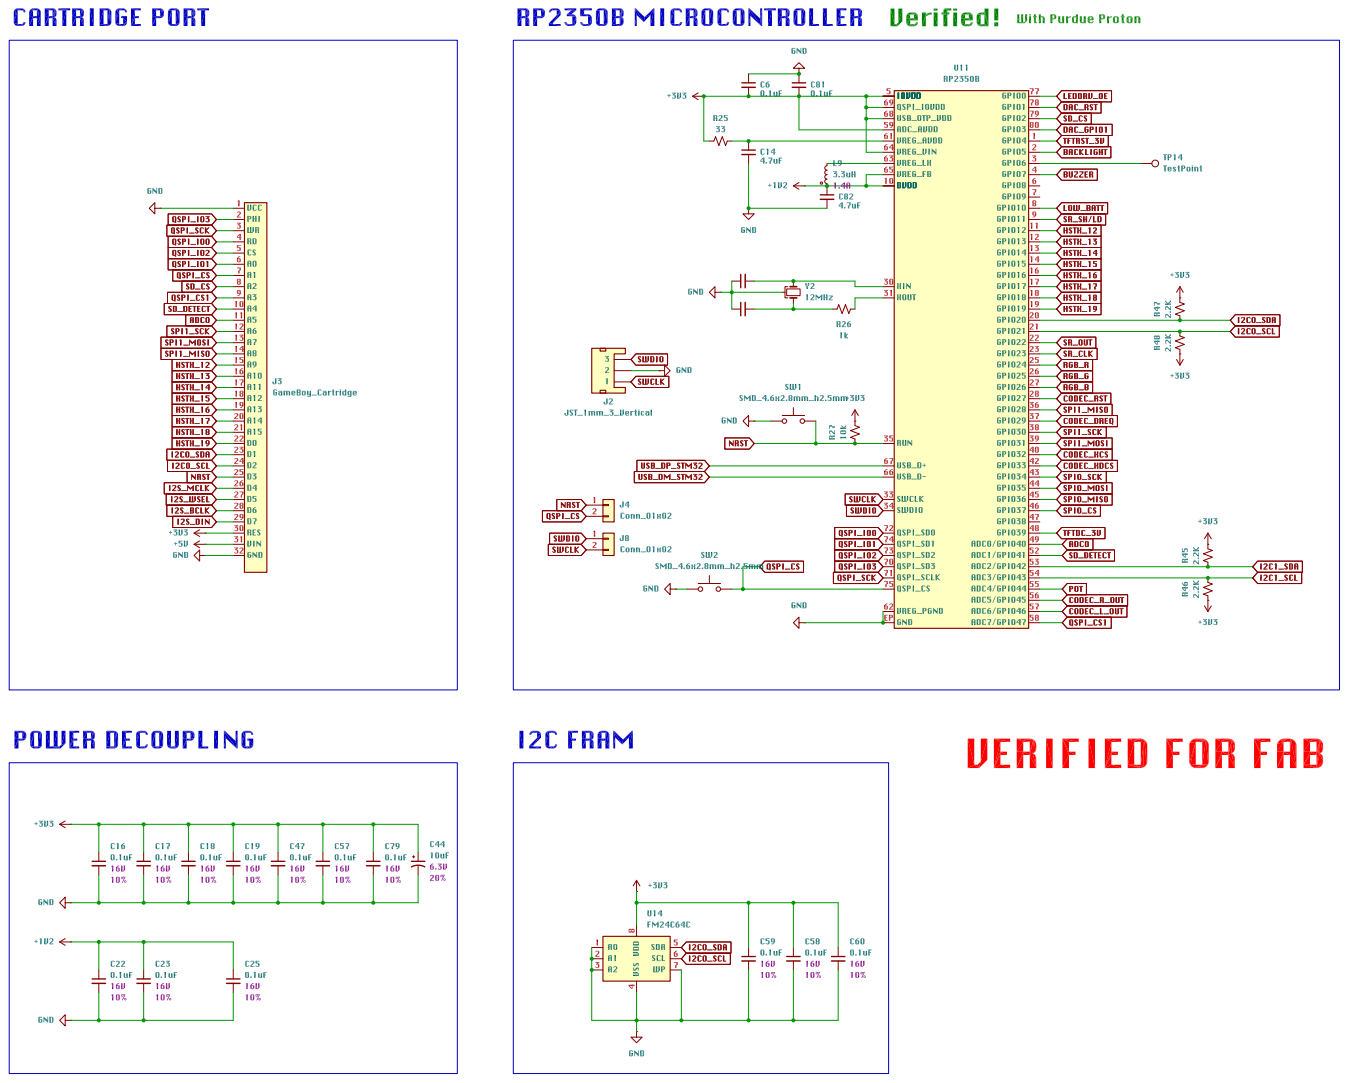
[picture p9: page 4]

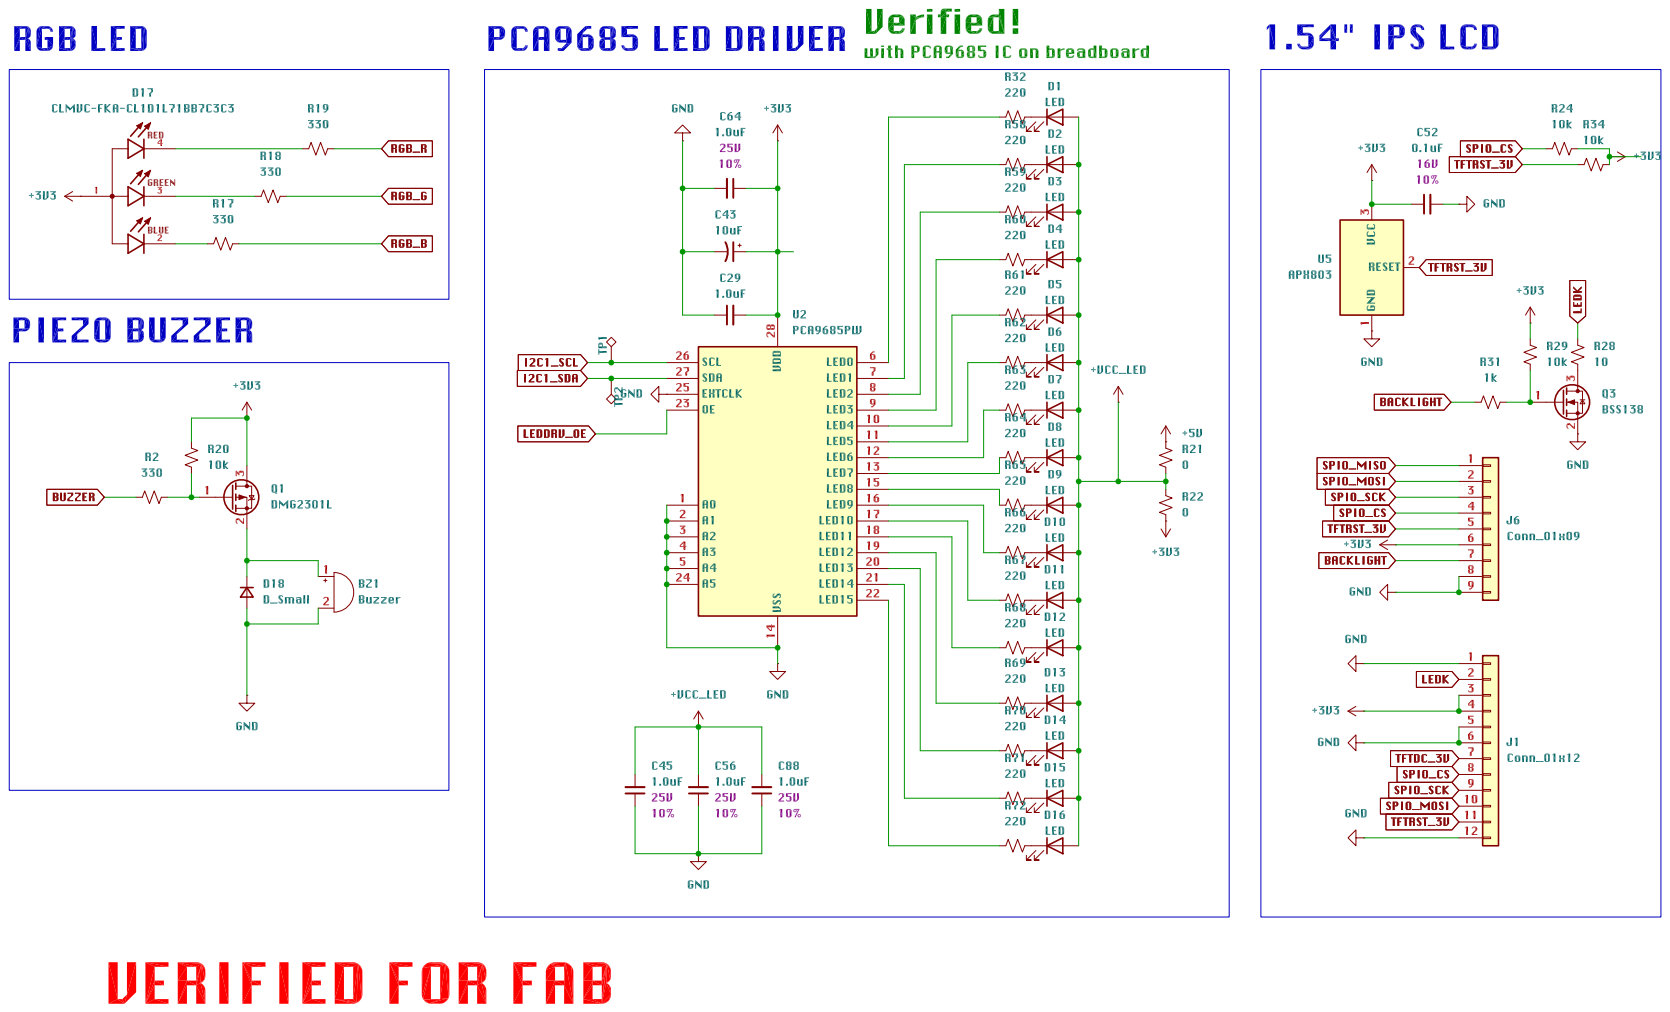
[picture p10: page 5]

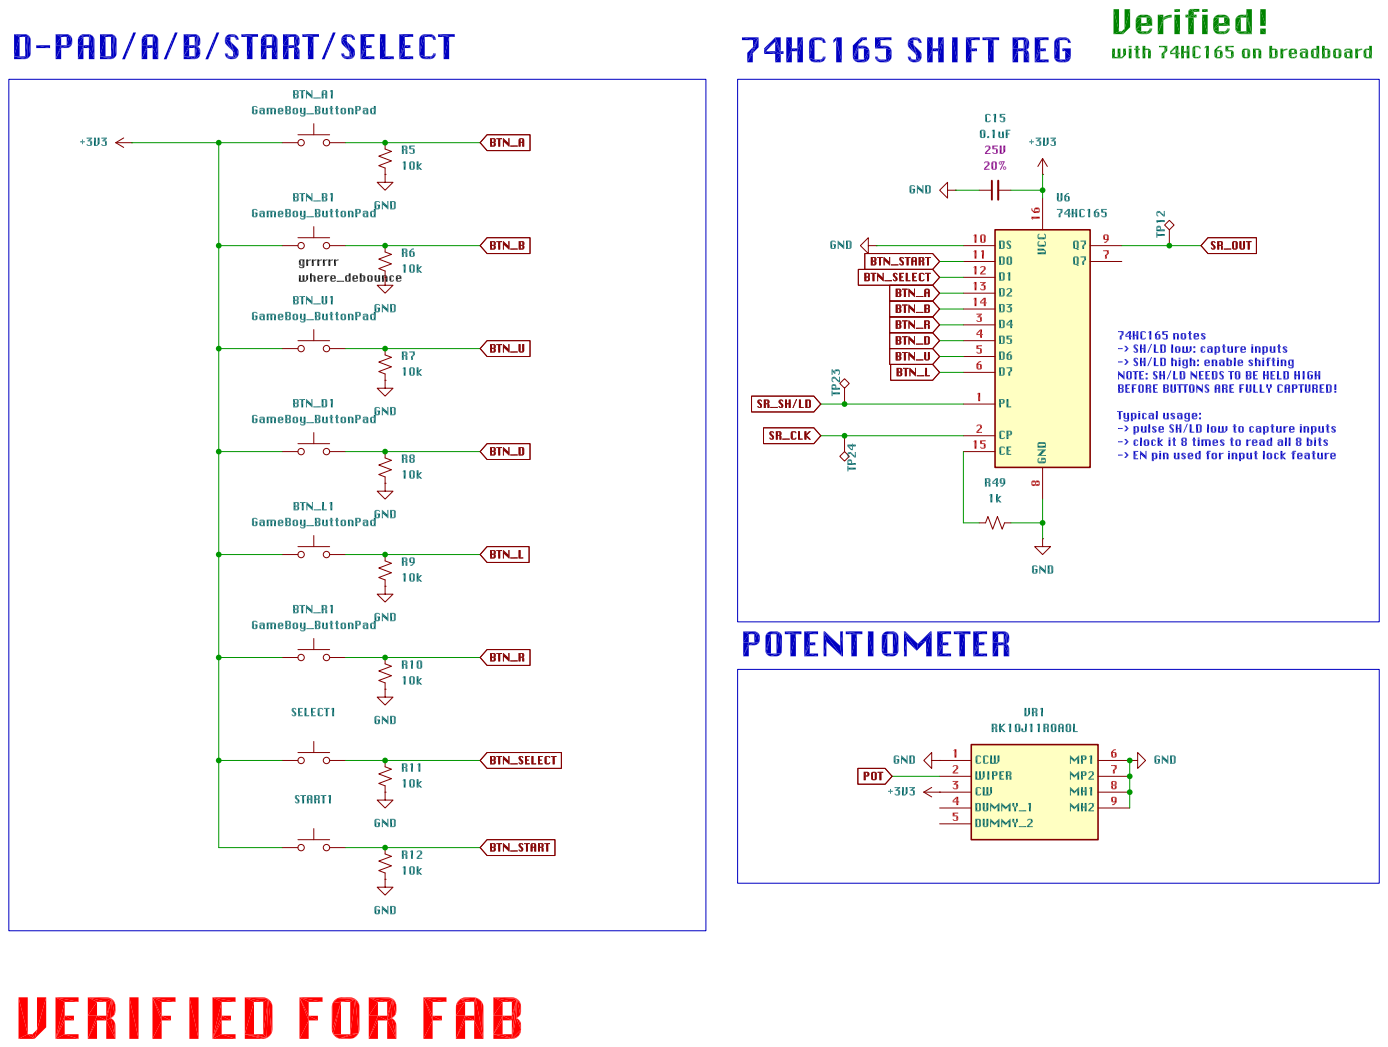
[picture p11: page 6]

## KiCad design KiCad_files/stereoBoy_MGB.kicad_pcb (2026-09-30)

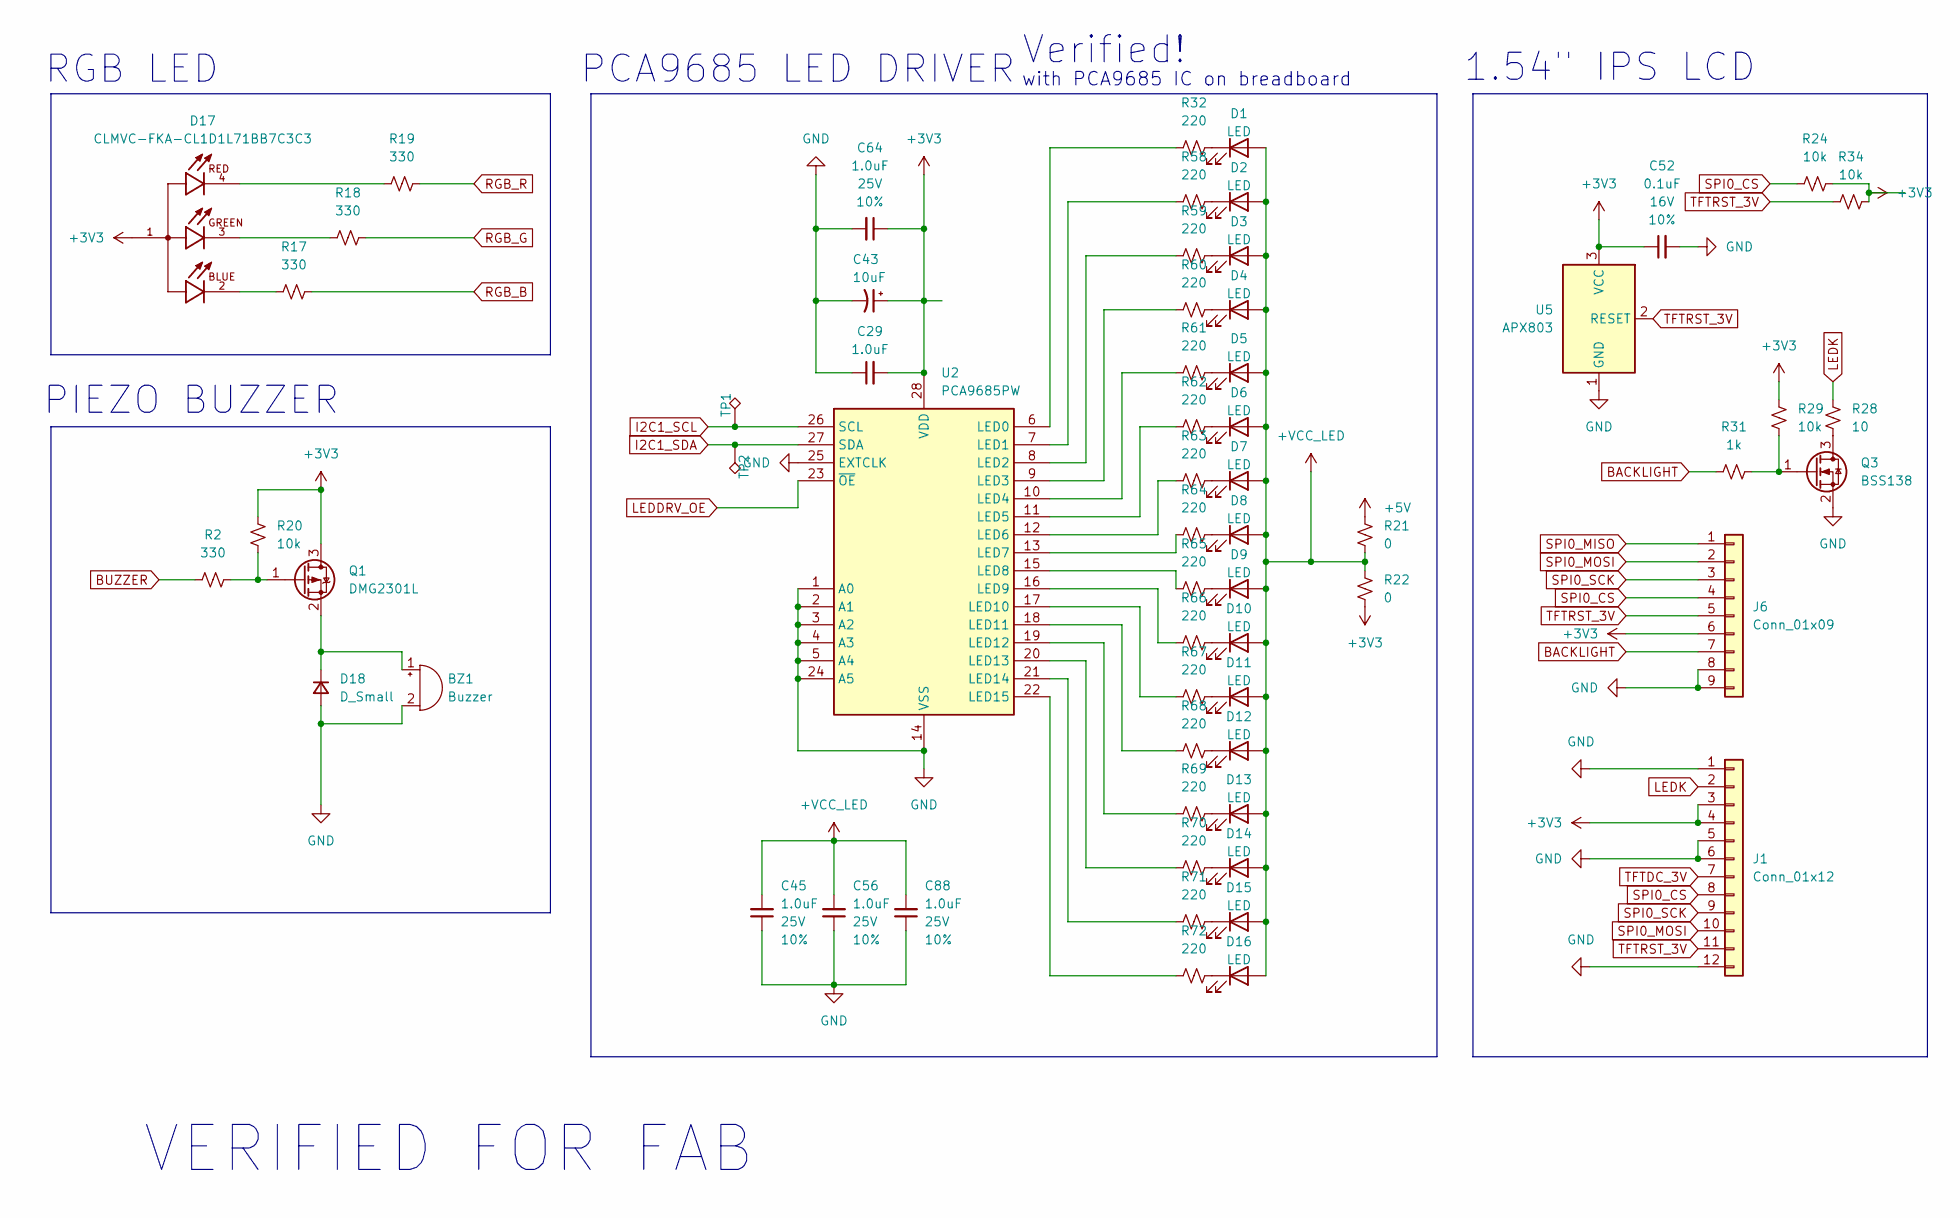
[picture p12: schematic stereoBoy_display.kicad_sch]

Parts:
BZ1: Buzzer; Buzzer_CUI_CPT-9019S-SMT
C29, C64: 1.0uF; C_0805_2012Metric; Voltage 25V; Tolerance 10%
C43: 10uF; CP_Elec_6.3x4.5; Voltage 6.3V; Tolerance 20%
C45, C56, C88: 1.0uF; C_1206_3216Metric; Voltage 25V; Tolerance 10%
C52: 0.1uF; C_0402_1005Metric; Voltage 16V; Tolerance 10%
D1, D2, D3, D4, D5, D6, D7, D8, D9, D10, D11, D12, D13, D14, D15, D16: LED; LED_D3.0mm
D17: CLMVC-FKA-CL1D1L71BB7C3C3; CREE_LED_2mm_x_2mm_Common_Anode; PARTREV 14
D18: D_Small; D_0603_1608Metric
J1: Conn_01x12; 1.54_IPS_FPC_Solder
J6: Conn_01x09; 1x09_P2.54mm
Q1: DMG2301L; SOT-23
Q3: BSS138; SOT-23
R2: 330; R_0603_1608Metric
R17, R18, R19: 330; R_0402_1005Metric
R20, R24, R29, R34: 10k; R_0603_1608Metric
R21, R22: 0; R_0603_1608Metric
R28: 10; R_0603_1608Metric
R31: 1k; R_0603_1608Metric
R32, R58, R59, R60, R61, R62, R63, R64, R65, R66, R67, R68, R69, R70, R71, R72: 220; R_0402_1005Metric
TP1, TP2: TestPoint_Alt; TestPoint_Pad_D1.0mm
U2: PCA9685PW; TSSOP-28_4.4x9.7mm_P0.65mm
U5: APX803; SOT-23

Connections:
+3V3: C29.2, C43.1, C52.1, C64.1, D17.1, J1.3, J1.4, J6.6, Q1.3 (D), R20.2, R22.1, R24.1, R29.2, R34.1, U2.28 (VDD), U5.3 (VCC); also elsewhere on the board
+5V: R21.2; also elsewhere on the board
+VCC_LED: C45.2, C56.2, C88.2, D1.2 (A), D2.2 (A), D3.2 (A), D4.2 (A), D5.2 (A), D6.2 (A), D7.2 (A), D8.2 (A), D9.2 (A), D10.2 (A), D11.2 (A), D12.2 (A), D13.2 (A), D14.2 (A), D15.2 (A), D16.2 (A), R21.1, R22.2
BACKLIGHT: J6.7, R31.2; also elsewhere on the board
BUZZER: R2.1; also elsewhere on the board
GND: BZ1.2 (-), C29.1, C43.2, C45.1, C52.2, C56.1, C64.2, C88.1, D18.2 (A), J1.1, J1.5, J1.6, J1.12, J6.8, J6.9, Q3.2 (S), U2.1 (A0), U2.2 (A1), U2.3 (A2), U2.4 (A3), U2.5 (A4), U2.14 (VSS), U2.24 (A5), U2.25 (EXTCLK), U5.1 (GND); also elsewhere on the board
I2C1_SCL: TP1.1, U2.26 (SCL); also elsewhere on the board
I2C1_SDA: TP2.1, U2.27 (SDA); also elsewhere on the board
LEDDRV_OE: U2.23 (~OE); also elsewhere on the board
LEDK: J1.2, R28.2
unnamed: BZ1.1 (+), D18.1 (K), Q1.2 (S)
unnamed: D1.1 (K), R32.2
unnamed: D2.1 (K), R58.2
unnamed: D3.1 (K), R59.2
unnamed: D4.1 (K), R60.2
unnamed: D5.1 (K), R61.2
unnamed: D6.1 (K), R62.2
unnamed: D7.1 (K), R63.2
unnamed: D8.1 (K), R64.2
unnamed: D9.1 (K), R65.2
unnamed: D10.1 (K), R66.2
unnamed: D11.1 (K), R67.2
unnamed: D12.1 (K), R68.2
unnamed: D13.1 (K), R69.2
unnamed: D14.1 (K), R70.2
unnamed: D15.1 (K), R71.2
unnamed: D16.1 (K), R72.2
unnamed: D17.2, R17.1
unnamed: D17.3, R18.1
unnamed: D17.4, R19.1
unnamed: Q1.1 (G), R2.2, R20.1
unnamed: Q3.3 (D), R28.1
unnamed: Q3.1 (G), R29.1, R31.1
unnamed: R32.1, U2.6 (LED0)
unnamed: R58.1, U2.7 (LED1)
unnamed: R59.1, U2.8 (LED2)
unnamed: R60.1, U2.9 (LED3)
unnamed: R61.1, U2.10 (LED4)
unnamed: R62.1, U2.11 (LED5)
unnamed: R63.1, U2.12 (LED6)
unnamed: R64.1, U2.13 (LED7)
unnamed: R65.1, U2.15 (LED8)
unnamed: R66.1, U2.16 (LED9)
unnamed: R67.1, U2.17 (LED10)
unnamed: R68.1, U2.18 (LED11)
unnamed: R69.1, U2.19 (LED12)
unnamed: R70.1, U2.20 (LED13)
unnamed: R71.1, U2.21 (LED14)
unnamed: R72.1, U2.22 (LED15)
RGB_B: R17.2; also elsewhere on the board
RGB_G: R18.2; also elsewhere on the board
RGB_R: R19.2; also elsewhere on the board
SPI0_CS: J1.8, J6.4, R24.2; also elsewhere on the board
SPI0_MISO: J6.1; also elsewhere on the board
SPI0_MOSI: J1.10, J6.2; also elsewhere on the board
SPI0_SCK: J1.9, J6.3; also elsewhere on the board
TFTDC_3V: J1.7; also elsewhere on the board
TFTRST_3V: J1.11, J6.5, R34.2, U5.2 (RESET); also elsewhere on the board

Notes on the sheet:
1.54" IPS LCD
with PCA9685 IC on breadboard
PIEZO BUZZER
RGB LED
Verified!
VERIFIED FOR FAB
PCA9685 LED DRIVER

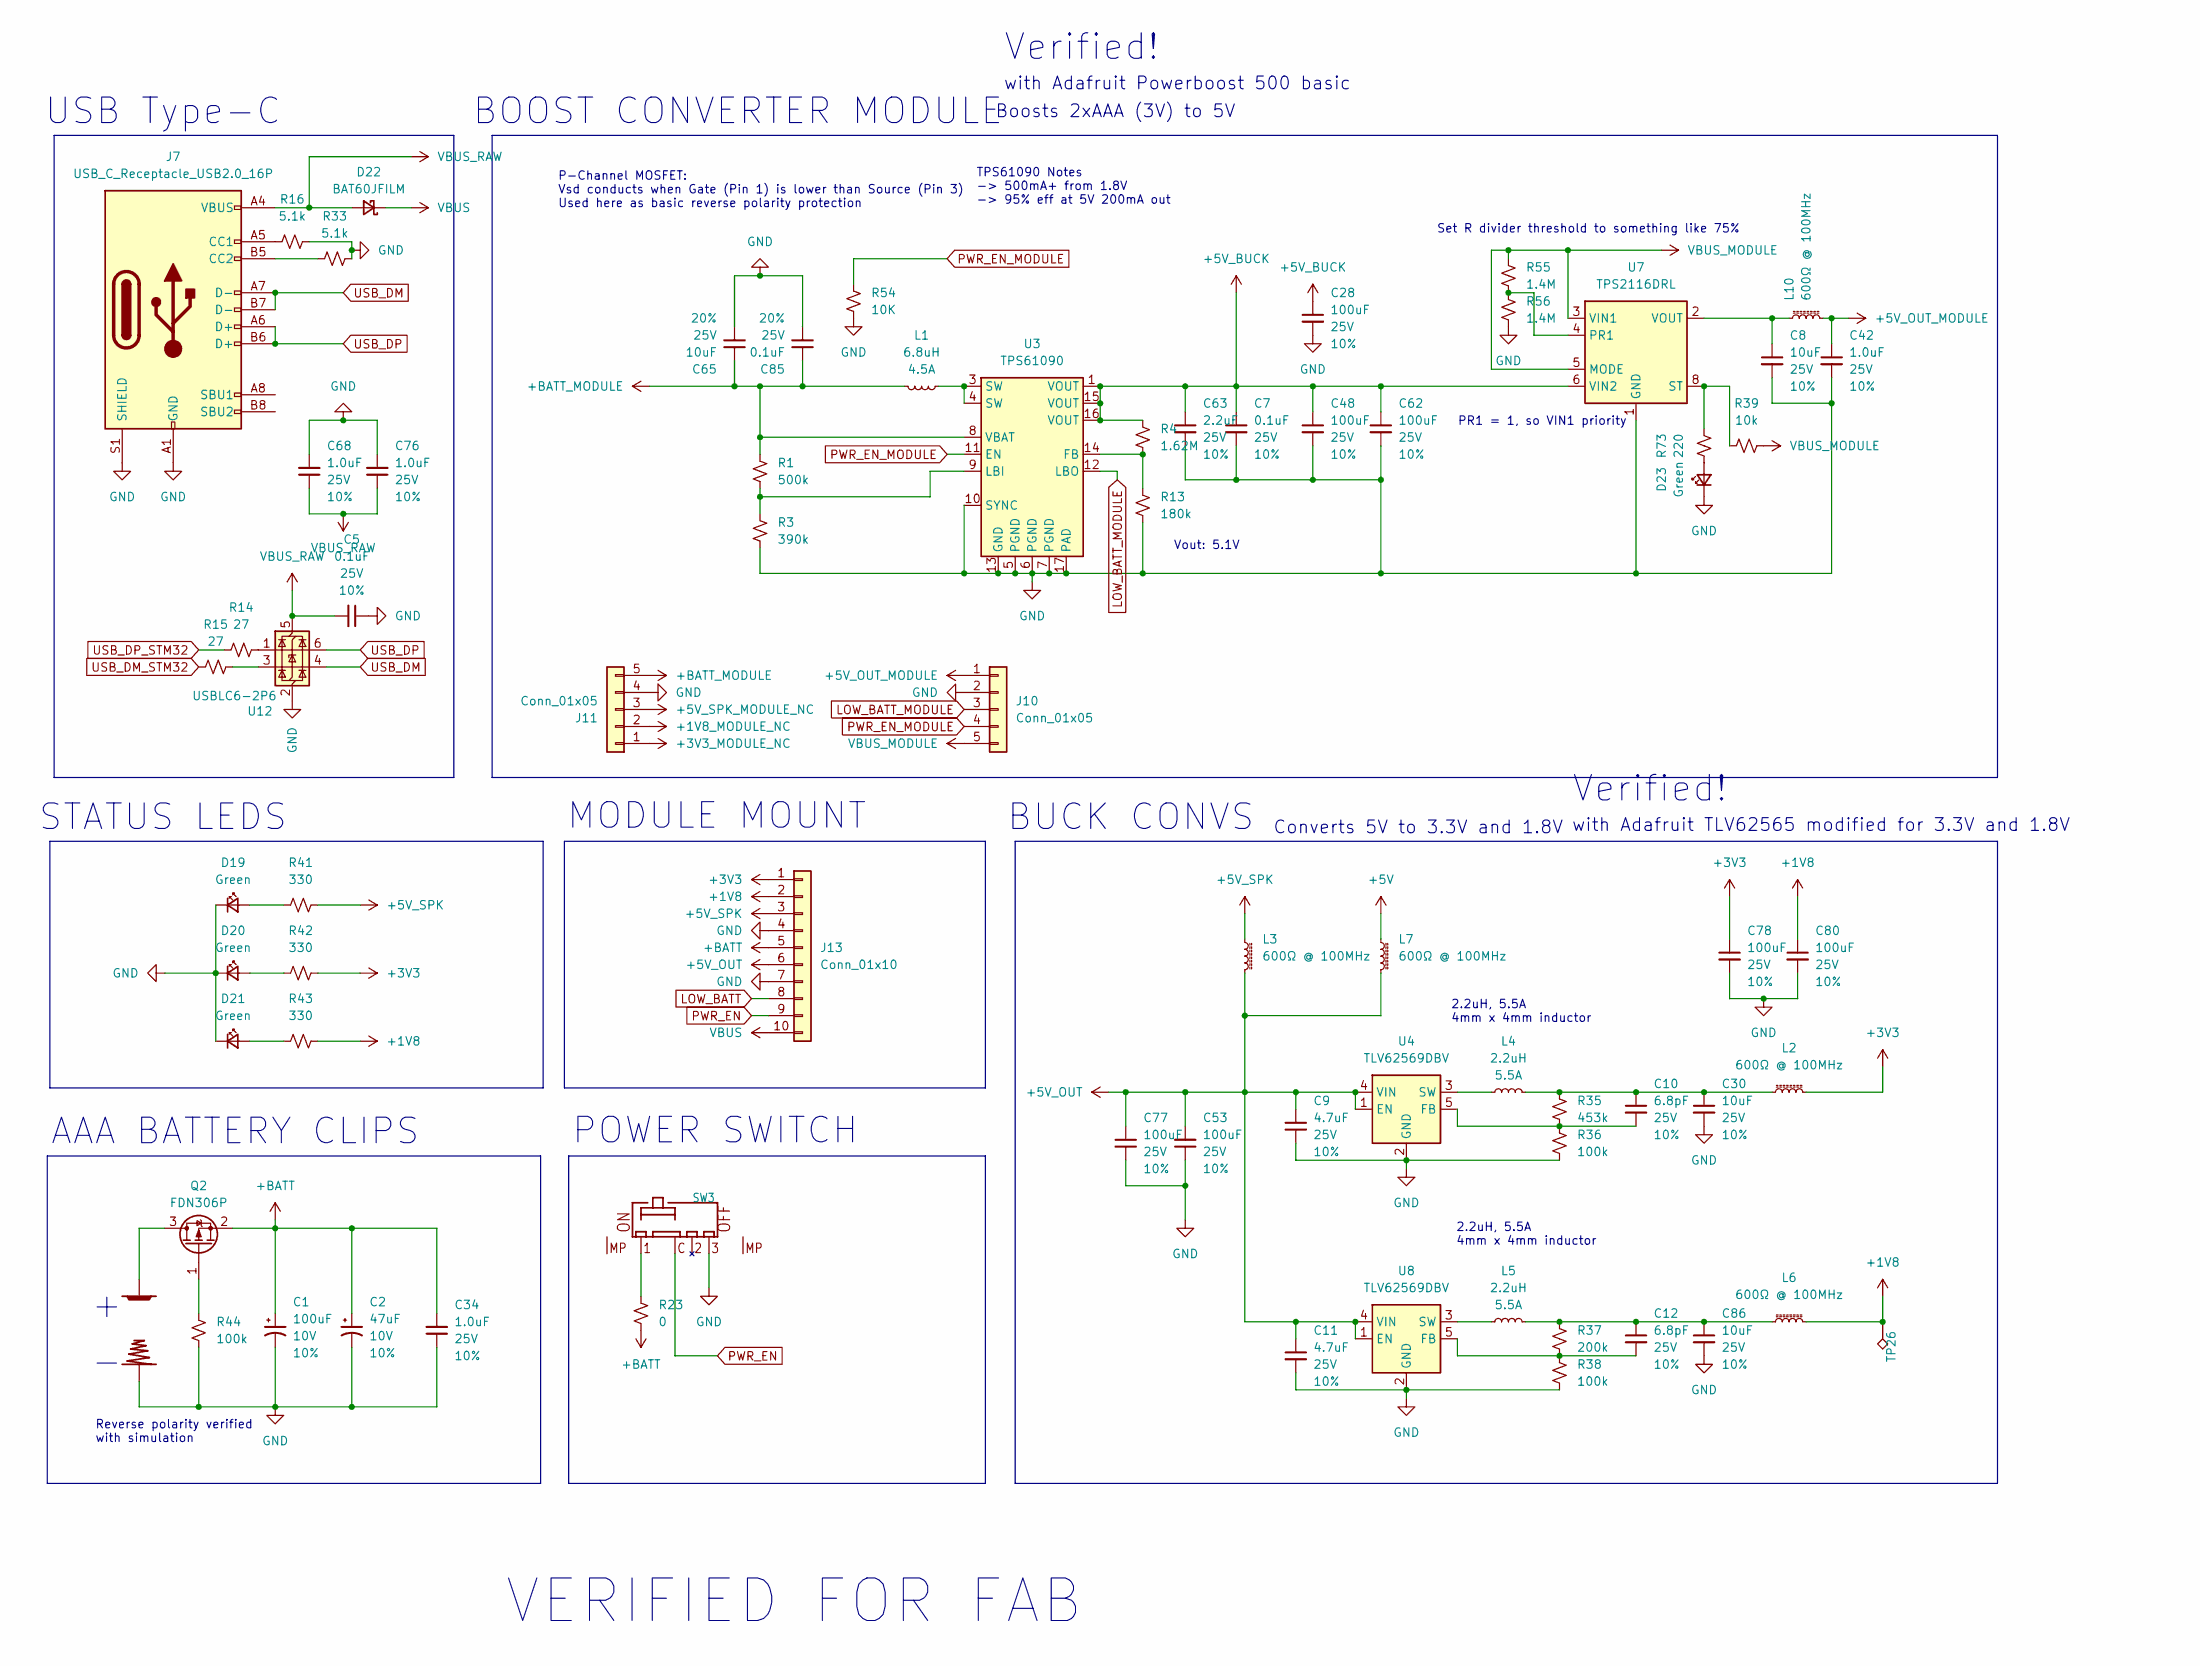
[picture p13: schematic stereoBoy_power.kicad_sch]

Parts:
+0: MGB+BATTERY4
-0: MGB-BATTERY4
C1: 100uF; CP_EIA-7343-15_Kemet-W_HandSolder; Voltage 10V; Tolerance 10%
C2: 47uF; CP_EIA-7343-15_Kemet-W_HandSolder; Voltage 10V; Tolerance 10%
C5: 0.1uF; C_0402_1005Metric; Voltage 25V; Tolerance 10%
C7: 0.1uF; C_0603_1608Metric; Voltage 25V; Tolerance 10%
C8: 10uF; C_1206_3216Metric; Voltage 25V; Tolerance 10%
C9, C11: 4.7uF; C_0805_2012Metric; Voltage 25V; Tolerance 10%
C10, C12: 6.8pF; C_0805_2012Metric; Voltage 25V; Tolerance 10%
C28: 100uF; C_0603_1608Metric; Voltage 25V; Tolerance 10%
C30, C86: 10uF; C_0805_2012Metric; Voltage 25V; Tolerance 10%
C34, C42: 1.0uF; C_1206_3216Metric; Voltage 25V; Tolerance 10%
C48, C53, C62, C77, C78, C80: 100uF; C_1206_3216Metric; Voltage 25V; Tolerance 10%
C63: 2.2uF; C_0603_1608Metric; Voltage 25V; Tolerance 10%
C65: 10uF; C_0603_1608Metric; Voltage 25V; Tolerance 20%
C68, C76: 1.0uF; C_0805_2012Metric; Voltage 25V; Tolerance 10%
C85: 0.1uF; C_0603_1608Metric; Voltage 25V; Tolerance 20%
D19, D20, D21: Green; LED_0603_1608Metric_Green
D22: BAT60JFILM; SOD-323
D23: Green; LED_1206_3216Metric_Green
J7: USB_C_Receptacle_USB2.0_16P; USB_C_Receptacle_GCT_USB4105-xx-A_16P_TopMnt_Horizontal
J10, J11: Conn_01x05; 1x05_P2.54mm
J13: Conn_01x10; StereoBoy_PSU
L1: 6.8uH; Inductor_7.3x6.6mm
L2, L6: 600Ω @ 100MHz; C_0603_1608Metric
L3, L7: 600Ω @ 100MHz; L_0603_1608Metric
L4, L5: 2.2uH; L_APV_ANR3012
L10: 600Ω @ 100MHz; L_0805_2012Metric
Q2: FDN306P; SOT-23
R1: 500k; R_0603_1608Metric
R3: 390k; R_0603_1608Metric
R4: 1.62M; C_0402_1005Metric
R13: 180k; C_0402_1005Metric
R14, R15: 27; C_0402_1005Metric
R16, R33: 5.1k; R_0603_1608Metric
R23: 0; R_0603_1608Metric
R35: 453k; R_0603_1608Metric
R36, R38: 100k; R_0603_1608Metric
R37: 200k; R_0603_1608Metric
R39: 10k; R_0603_1608Metric
R41, R42, R43: 330; R_0402_1005Metric
R44: 100k; R_0805_2012Metric
R54: 10K; R_0402_1005Metric
R55, R56: 1.4M; R_0603_1608Metric
R73: 220; R_0603_1608Metric
SW3: MGB-SW1; GBP_Power_Switch
TP26: TestPoint_Alt; TestPoint_Pad_D1.0mm
U3: TPS61090; Texas_RSA_VQFN-16-1EP_4x4mm_P0.65mm_EP2.7x2.7mm_ThermalVias
U4, U8: TLV62569DBV; SOT-23-5
U7: TPS2116DRL; SOT-583-8
U12: USBLC6-2P6; SOT-666

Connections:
+1V8: C80.1, J13.2, L6.2, R43.2, TP26.1; also elsewhere on the board
+1V8_MODULE_NC: J11.2
+3V3: C78.1, J13.1, L2.2, R42.2; also elsewhere on the board
+3V3_MODULE_NC: J11.1
+5V: L7.1; also elsewhere on the board
+5V_BUCK: C7.1, C28.1, C48.1, C62.1, C63.1, R4.1, U3.1 (VOUT), U3.15 (VOUT), U3.16 (VOUT), U7.6 (VIN2)
+5V_OUT: C9.1, C11.1, C53.2, C77.1, J13.6, L3.2, L7.2, U4.1 (EN), U4.4 (VIN), U8.1 (EN), U8.4 (VIN)
+5V_OUT_MODULE: C42.1, J10.1, L10.2
+5V_SPK: J13.3, L3.1, R41.2; also elsewhere on the board
+5V_SPK_MODULE_NC: J11.3
+BATT: C1.1, C2.1, C34.2, J13.5, Q2.2 (S), R23.1
+BATT_MODULE: C65.1, C85.1, J11.5, L1.2, R1.1, U3.8 (VBAT)
GND: -0.P$1, -0.P$3, -0.P$4, C1.2, C2.2, C5.1, C7.2, C8.2, C9.2, C11.2, C28.2, C30.2, C34.1, C42.2, C48.2, C53.1, C62.2, C63.2, C65.2, C68.2, C76.2, C77.2, C78.2, C80.2, C85.2, C86.2, D19.1 (K), D20.1 (K), D21.1 (K), D23.1 (K), J7.A1 (GND), J7.A12 (GND), J7.B1 (GND), J7.B12 (GND), J7.S1 (SHIELD), J10.2, J11.4, J13.4, J13.7, R3.2, R13.2, R16.2, R33.2, R36.2, R38.2, R44.1, R54.2, R56.2, SW3.P$3 (3), U3.5 (PGND), U3.6 (PGND), U3.7 (PGND), U3.10 (SYNC), U3.13 (GND), U3.17 (PAD), U4.2 (GND), U7.1 (GND), U8.2 (GND), U12.2 (GND); also elsewhere on the board
LOW_BATT: J13.8; also elsewhere on the board
LOW_BATT_MODULE: J10.3, U3.12 (LBO)
unnamed: C8.1, L10.1, U7.2 (VOUT), U7.7 (VOUT)
unnamed: C10.1, C30.1, L2.1, L4.2, R35.1
unnamed: C12.1, C86.1, L5.2, L6.1, R37.1
unnamed: D19.2 (A), R41.1
unnamed: D20.2 (A), R42.1
unnamed: D21.2 (A), R43.1
unnamed: D23.2 (A), R73.1
unnamed: J7.A5 (CC1), R16.1
unnamed: J7.B5 (CC2), R33.1
unnamed: L1.1, U3.3 (SW), U3.4 (SW)
unnamed: +0.P$1, +0.P$2, +0.P$3, Q2.3 (D)
unnamed: Q2.1 (G), R44.2
unnamed: R14.2, U12.1 (I/O1)
unnamed: R15.2, U12.3 (I/O2)
unnamed: R23.2, SW3.P$1 (1)
unnamed: R4.2, R13.1, U3.14 (FB)
unnamed: R1.2, R3.1, U3.9 (LBI)
unnamed: C10.2, R35.2, R36.1, U4.5 (FB)
unnamed: L4.1, U4.3 (SW)
unnamed: R55.2, R56.1, U7.4 (PR1)
unnamed: R39.1, R73.2, U7.8 (ST)
unnamed: C12.2, R37.2, R38.1, U8.5 (FB)
unnamed: L5.1, U8.3 (SW)
PWR_EN: J13.9, SW3.P$C (C)
PWR_EN_MODULE: J10.4, R54.1, U3.11 (EN)
USB_DM: J7.A7 (D-), J7.B7 (D-), U12.4 (I/O2)
USB_DM_STM32: R15.1; also elsewhere on the board
USB_DP: J7.A6 (D+), J7.B6 (D+), U12.6 (I/O1)
USB_DP_STM32: R14.1; also elsewhere on the board
VBUS: D22.1 (K), J13.10
VBUS_MODULE: J10.5, R39.2, R55.1, U7.3 (VIN1), U7.5 (MODE)
VBUS_RAW: C5.2, C68.1, C76.1, D22.2 (A), J7.A4 (VBUS), J7.A9 (VBUS), J7.B4 (VBUS), J7.B9 (VBUS), U12.5 (VBUS)

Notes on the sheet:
with Adafruit Powerboost 500 basic
Vout: 5.1V
AAA BATTERY CLIPS
2.2uH, 5.5A 4mm x 4mm inductor
MODULE MOUNT
BUCK CONVS
STATUS LEDS
with Adafruit TLV62565 modified for 3.3V and 1.8V
Converts 5V to 3.3V and 1.8V
PR1 = 1, so VIN1 priority
POWER SWITCH
Reverse polarity verified with simulation
Boosts 2xAAA (3V) to 5V
Set R divider threshold to something like 75%
P-Channel MOSFET: Vsd conducts when Gate (Pin 1) is lower than Source (Pin 3) Used here as basic reverse polarity protection
USB Type-C
BOOST CONVERTER MODULE
VERIFIED FOR FAB
Verified!
TPS61090 Notes -> 500mA+ from 1.8V -> 95% eff at 5V 200mA out

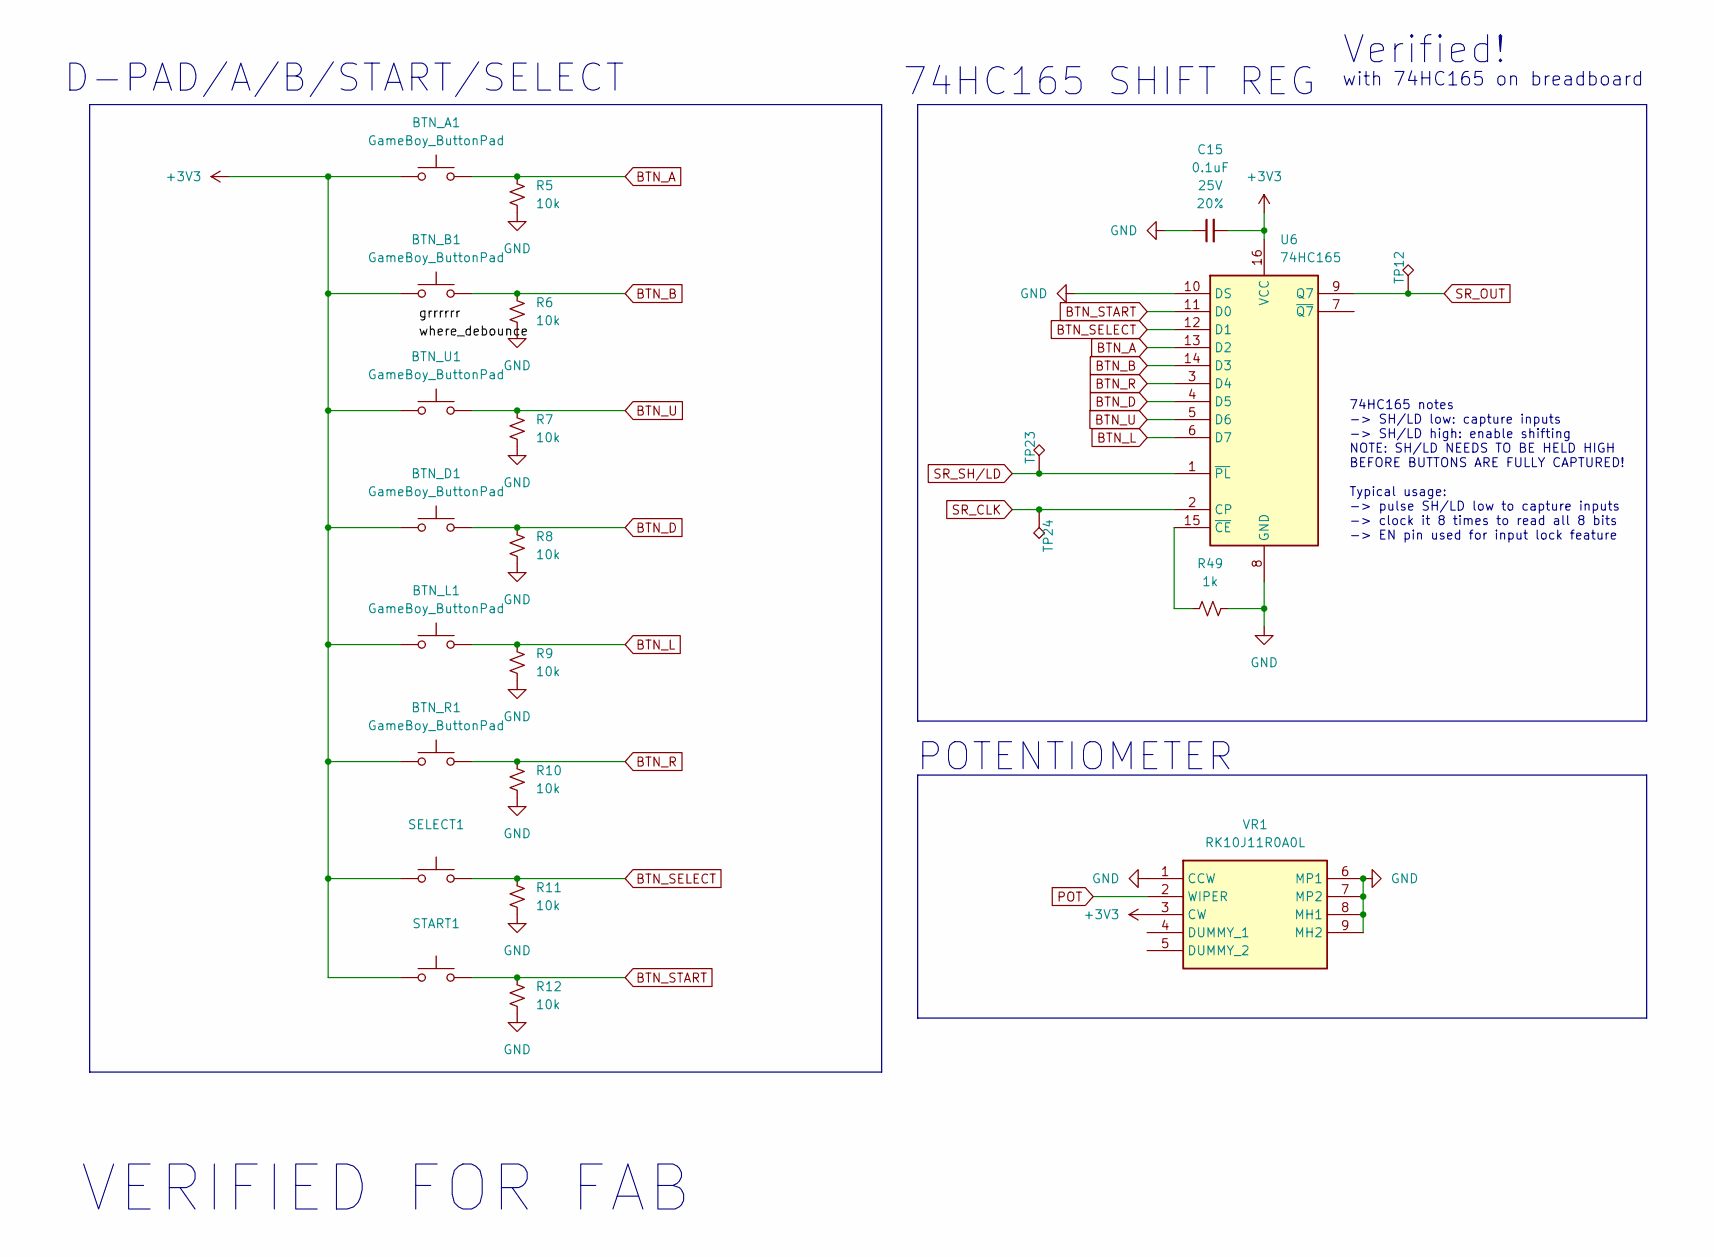
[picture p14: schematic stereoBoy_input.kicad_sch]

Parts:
BTN_A1: GameBoy_ButtonPad; GameBoy_A_B_Pad
BTN_B1: GameBoy_ButtonPad; GameBoy_A_B_Pad
BTN_D1: GameBoy_ButtonPad; GameBoy_DPad
BTN_L1: GameBoy_ButtonPad; GameBoy_DPad
BTN_R1: GameBoy_ButtonPad; GameBoy_DPad
BTN_U1: GameBoy_ButtonPad; GameBoy_DPad
C15: 0.1uF; C_0402_1005Metric; Voltage 25V; Tolerance 20%
R5, R6, R7, R8, R9, R10, R11, R12: 10k; R_0603_1608Metric
R49: 1k; R_0402_1005Metric
SELECT1: SMD_6x3.5mm_h2.5mm; GameBoy_Select_Start; Mfg Part# 8-004 SMD Button 8x3.6mm Height=2.5mm
START1: SMD_6x3.5mm_h2.5mm; GameBoy_Select_Start; Mfg Part# 8-004 SMD Button 8x3.6mm Height=2.5mm
TP12, TP23, TP24: TestPoint_Alt; TestPoint_Pad_D1.0mm
U6: 74HC165; TSSOP-16_4.4x5mm_P0.65mm
VR1: RK10J11R0A0L; Manufacturer_Part_Number RK10J11R0A0L; Mouser Part Number 688-RK10J11R0A0L

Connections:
+3V3: BTN_A1.1, BTN_B1.1, BTN_D1.1, BTN_L1.1, BTN_R1.1, BTN_U1.1, C15.2, SELECT1.1, START1.1, U6.16 (VCC), VR1.3 (CW); also elsewhere on the board
BTN_A: BTN_A1.2, R5.2, U6.13 (D2)
BTN_B: BTN_B1.2, R6.2, U6.14 (D3)
BTN_D: BTN_D1.2, R8.2, U6.4 (D5)
BTN_L: BTN_L1.2, R9.2, U6.6 (D7)
BTN_R: BTN_R1.2, R10.2, U6.3 (D4)
BTN_SELECT: R11.2, SELECT1.2, U6.12 (D1)
BTN_START: R12.2, START1.2, U6.11 (D0)
BTN_U: BTN_U1.2, R7.2, U6.5 (D6)
GND: C15.1, R5.1, R6.1, R7.1, R8.1, R9.1, R10.1, R11.1, R12.1, R49.2, U6.8 (GND), U6.10 (DS), VR1.1 (CCW), VR1.6 (MP1), VR1.7 (MP2), VR1.8 (MH1), VR1.9 (MH2); also elsewhere on the board
unnamed: R49.1, U6.15 (~CE)
POT: VR1.2 (WIPER); also elsewhere on the board
SR_CLK: TP24.1, U6.2 (CP); also elsewhere on the board
SR_OUT: TP12.1, U6.9 (Q7); also elsewhere on the board
SR_SH/LD: TP23.1, U6.1 (~PL); also elsewhere on the board

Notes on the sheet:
74HC165 SHIFT REG
Verified!
D-PAD/A/B/START/SELECT
VERIFIED FOR FAB
74HC165 notes -> SH/LD low: capture inputs -> SH/LD high: enable shifting NOTE: SH/LD NEEDS TO BE HELD HIGH BEFORE BUTTONS ARE FULLY CAPTURED! Typical usage: -> pulse SH/LD low to capture inputs -> clock it 8 times to read all 8 bits -> EN pin used for input lock feature
with 74HC165 on breadboard
POTENTIOMETER

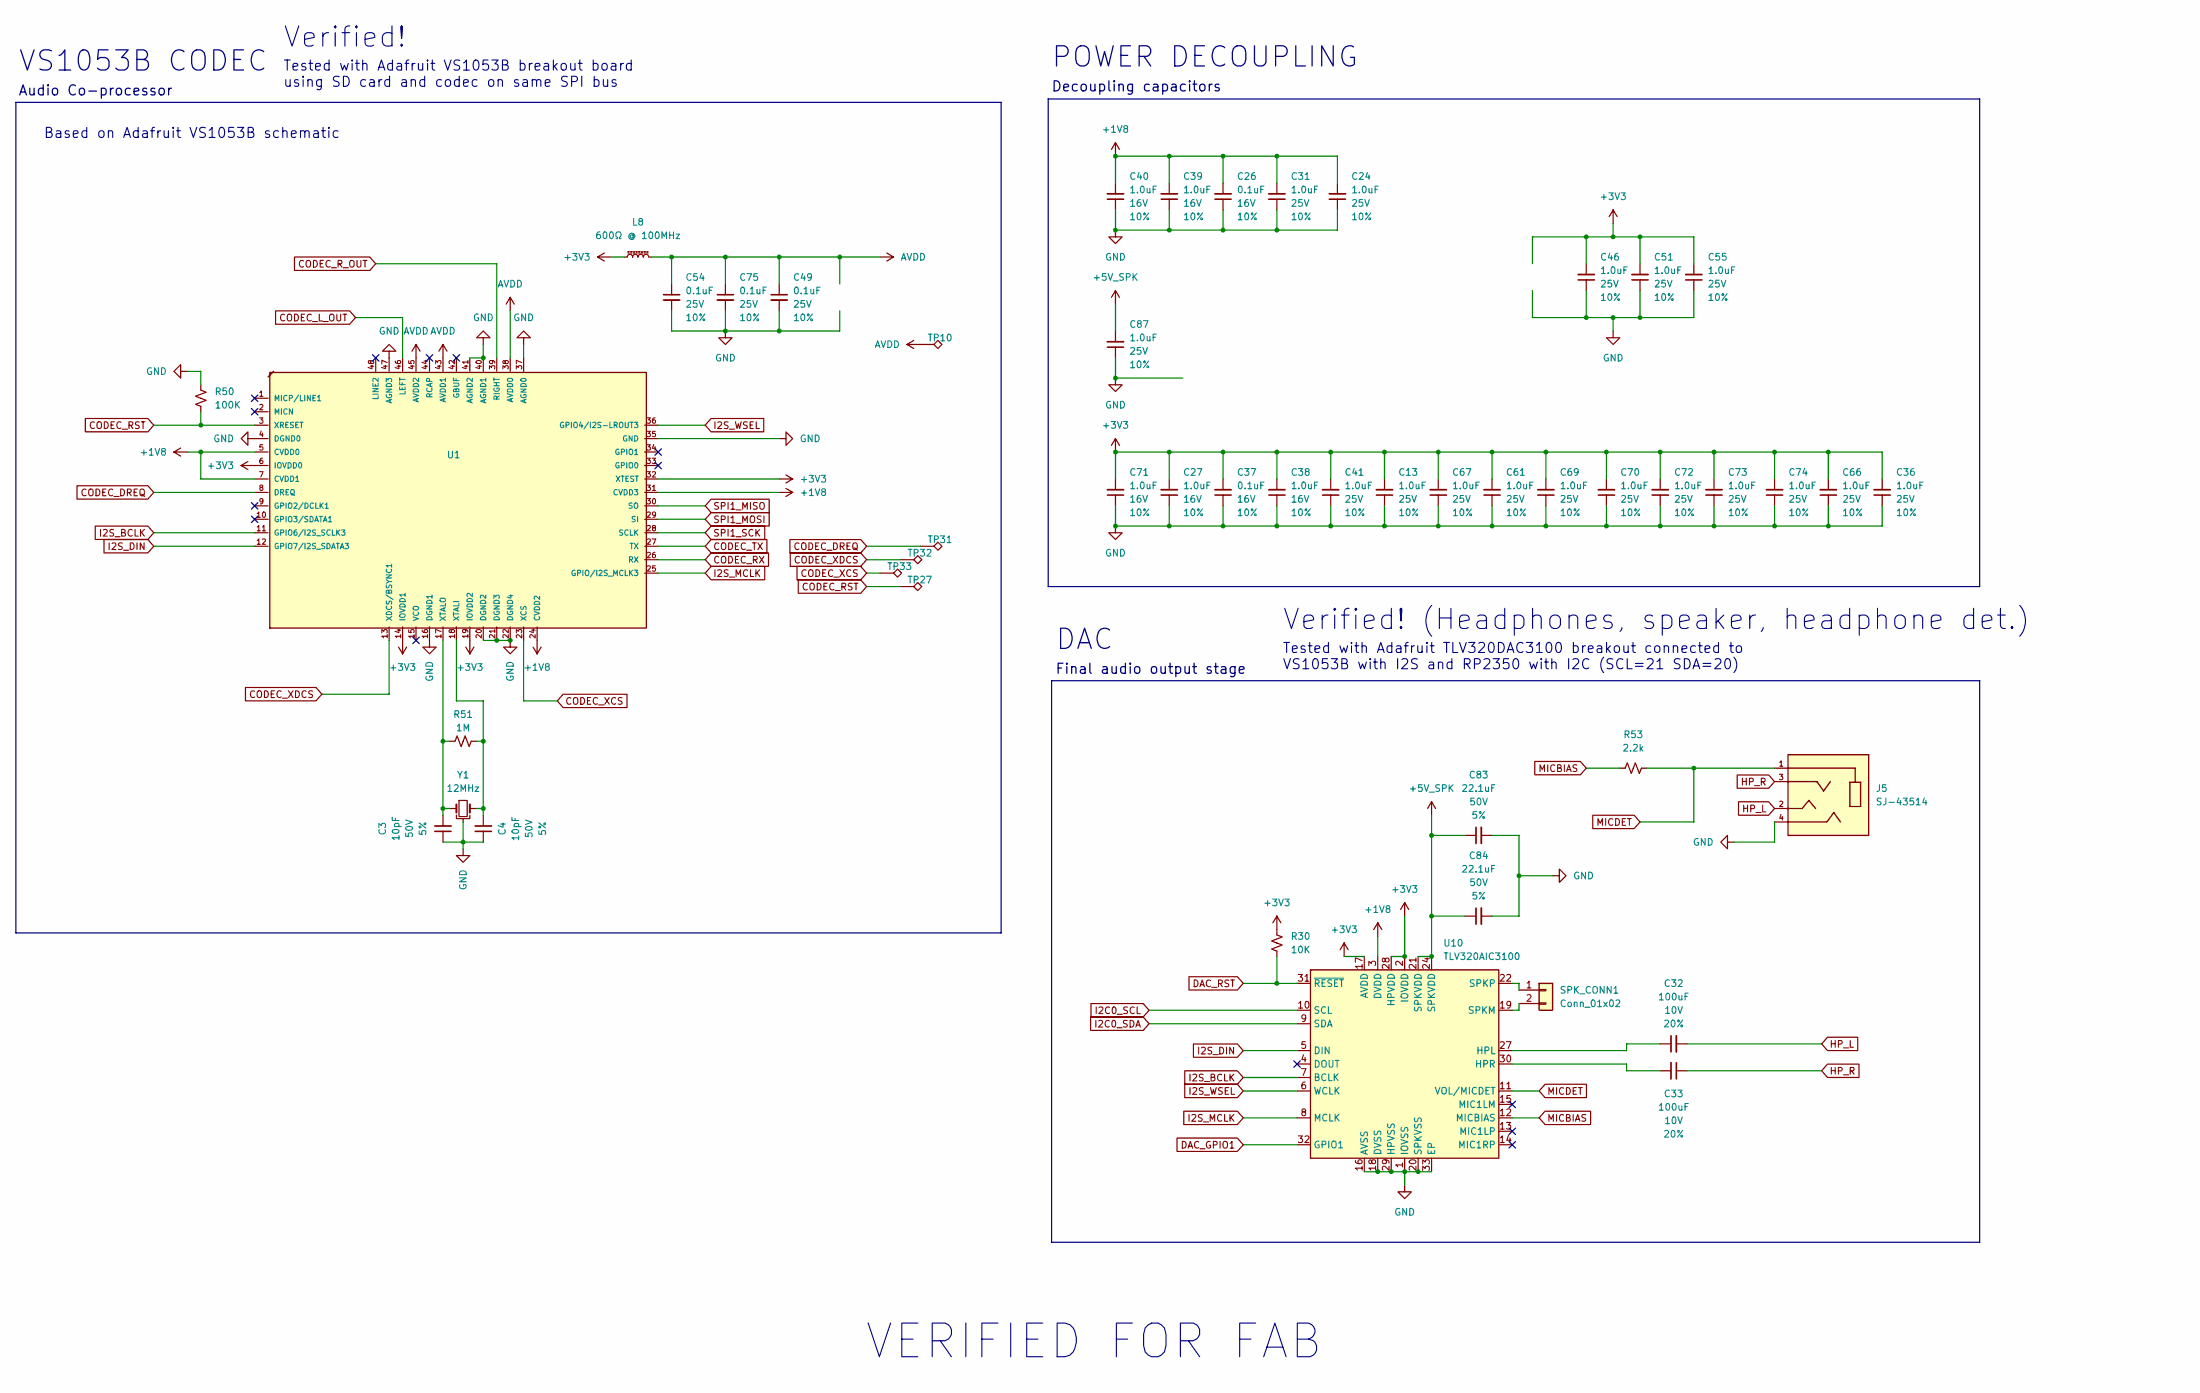
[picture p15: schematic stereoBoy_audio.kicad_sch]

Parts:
C3, C4: 10pF; C_0402_1005Metric; Voltage 50V; Tolerance 5%
C13, C24, C31, C36, C41: 1.0uF; C_0402_1005Metric; Voltage 25V; Tolerance 10%
C26, C37: 0.1uF; C_0402_1005Metric; Voltage 16V; Tolerance 10%
C27, C38, C39, C40, C71: 1.0uF; C_0402_1005Metric; Voltage 16V; Tolerance 10%
C32, C33: 100uF; C_1206_3216Metric; Voltage 10V; Tolerance 20%
C46, C51, C55, C66, C67, C70, C72, C73, C74: 1.0uF; C_1206_3216Metric; Voltage 25V; Tolerance 10%
C49, C75: 0.1uF; C_0402_1005Metric; Voltage 25V; Tolerance 10%
C54: 0.1uF; C_0603_1608Metric; Voltage 25V; Tolerance 10%
C61, C69, C87: 1.0uF; C_0805_2012Metric; Voltage 25V; Tolerance 10%
C83, C84: 22.1uF; C_0402_1005Metric; Voltage 50V; Tolerance 5%
J5: SJ-43514; SJ_43514; PART_REV 1.04
L8: 600Ω @ 100MHz; C_0603_1608Metric
R30: 10K; R_0402_1005Metric
R50: 100K; R_0402_1005Metric
R51: 1M; R_0402_1005Metric
R53: 2.2k; R_0402_1005Metric
SPK_CONN1: Conn_01x02; 1x02
TP10, TP27, TP31, TP32, TP33: TestPoint_Alt; TestPoint_Pad_D1.0mm
U1: VS1053B-lqfp48; VS1053b; MPN VS1053B
U10: TLV320AIC3100; VQFN-32-1EP_5x5mm_P0.5mm_EP3.5x3.5mm
Y1: 12MHz; Crystal_SMD_3225-4Pin_3.2x2.5mm

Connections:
+1V8: C24.2, C26.2, C31.2, C39.2, C40.2, U1.5 (CVDD0), U1.7 (CVDD1), U1.24 (CVDD2), U1.31 (CVDD3), U10.3 (DVDD); also elsewhere on the board
+3V3: C13.2, C27.2, C36.2, C37.2, C38.2, C41.2, C46.2, C51.2, C55.2, C61.2, C66.2, C67.2, C69.2, C70.2, C71.2, C72.2, C73.2, C74.2, L8.1, R30.2, U1.6 (IOVDD0), U1.14 (IOVDD1), U1.19 (IOVDD2), U1.32 (XTEST), U10.2 (IOVDD), U10.17 (AVDD), U10.28 (HPVDD); also elsewhere on the board
+5V_SPK: C83.1, C84.1, C87.2, U10.21 (SPKVDD), U10.24 (SPKVDD); also elsewhere on the board
AVDD: C49.1, C54.1, C75.1, L8.2, TP10.1, U1.38 (AVDD0), U1.43 (AVDD1), U1.45 (AVDD2)
CODEC_DREQ: TP31.1, U1.8 (DREQ); also elsewhere on the board
CODEC_L_OUT: U1.46 (LEFT); also elsewhere on the board
CODEC_RST: R50.1, TP27.1, U1.3 (XRESET); also elsewhere on the board
CODEC_RX: U1.26 (RX)
CODEC_R_OUT: U1.39 (RIGHT); also elsewhere on the board
CODEC_TX: U1.27 (TX)
CODEC_XCS: TP33.1, U1.23 (XCS); also elsewhere on the board
CODEC_XDCS: TP32.1, U1.13 (XDCS/BSYNC1); also elsewhere on the board
DAC_GPIO1: U10.32 (GPIO1); also elsewhere on the board
DAC_RST: R30.1, U10.31 (~RESET); also elsewhere on the board
GND: C3.1, C4.1, C13.1, C24.1, C26.1, C27.1, C31.1, C36.1, C37.1, C38.1, C39.1, C40.1, C41.1, C46.1, C49.2, C51.1, C54.2, C55.1, C61.1, C66.1, C67.1, C69.1, C70.1, C71.1, C72.1, C73.1, C74.1, C75.2, C83.2, C84.2, C87.1, J5.4, R50.2, U1.4 (DGND0), U1.16 (DGND1), U1.20 (DGND2), U1.21 (DGND3), U1.22 (DGND4), U1.35 (GND), U1.37 (AGND0), U1.40 (AGND1), U1.41 (AGND2), U1.47 (AGND3), U10.1 (IOVSS), U10.16 (AVSS), U10.18 (DVSS), U10.20 (SPKVSS), U10.25 (SPKVSS), U10.29 (HPVSS), U10.33 (EP), Y1.2, Y1.4; also elsewhere on the board
HP_L: C32.2, J5.2
HP_R: C33.1, J5.3
I2C0_SCL: U10.10 (SCL); also elsewhere on the board
I2C0_SDA: U10.9 (SDA); also elsewhere on the board
I2S_BCLK: U1.11 (GPIO6/I2S_SCLK3), U10.7 (BCLK); also elsewhere on the board
I2S_DIN: U1.12 (GPIO7/I2S_SDATA3), U10.5 (DIN); also elsewhere on the board
I2S_MCLK: U1.25 (GPIO/I2S_MCLK3), U10.8 (MCLK); also elsewhere on the board
I2S_WSEL: U1.36 (GPIO4/I2S-LROUT3), U10.6 (WCLK); also elsewhere on the board
MICBIAS: R53.2, U10.12 (MICBIAS)
MICDET: J5.1, R53.1, U10.11 (VOL/MICDET)
unnamed: SPK_CONN1.1, U10.22 (SPKP), U10.26 (SPKP)
unnamed: SPK_CONN1.2, U10.19 (SPKM), U10.23 (SPKM)
unnamed: C4.2, R51.1, U1.18 (XTALI), Y1.3
unnamed: C3.2, R51.2, U1.17 (XTALO), Y1.1
unnamed: C32.1, U10.27 (HPL)
unnamed: C33.2, U10.30 (HPR)
SPI1_MISO: U1.30 (SO); also elsewhere on the board
SPI1_MOSI: U1.29 (SI); also elsewhere on the board
SPI1_SCK: U1.28 (SCLK); also elsewhere on the board

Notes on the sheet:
DAC
VERIFIED FOR FAB
POWER DECOUPLING
Tested with Adafruit TLV320DAC3100 breakout connected to VS1053B with I2S and RP2350 with I2C (SCL=21 SDA=20)
Verified!
Tested with Adafruit VS1053B breakout board using SD card and codec on same SPI bus
Based on Adafruit VS1053B schematic
Decoupling capacitors
Audio Co-processor
VS1053B CODEC
Final audio output stage
Verified! (Headphones, speaker, headphone det.)

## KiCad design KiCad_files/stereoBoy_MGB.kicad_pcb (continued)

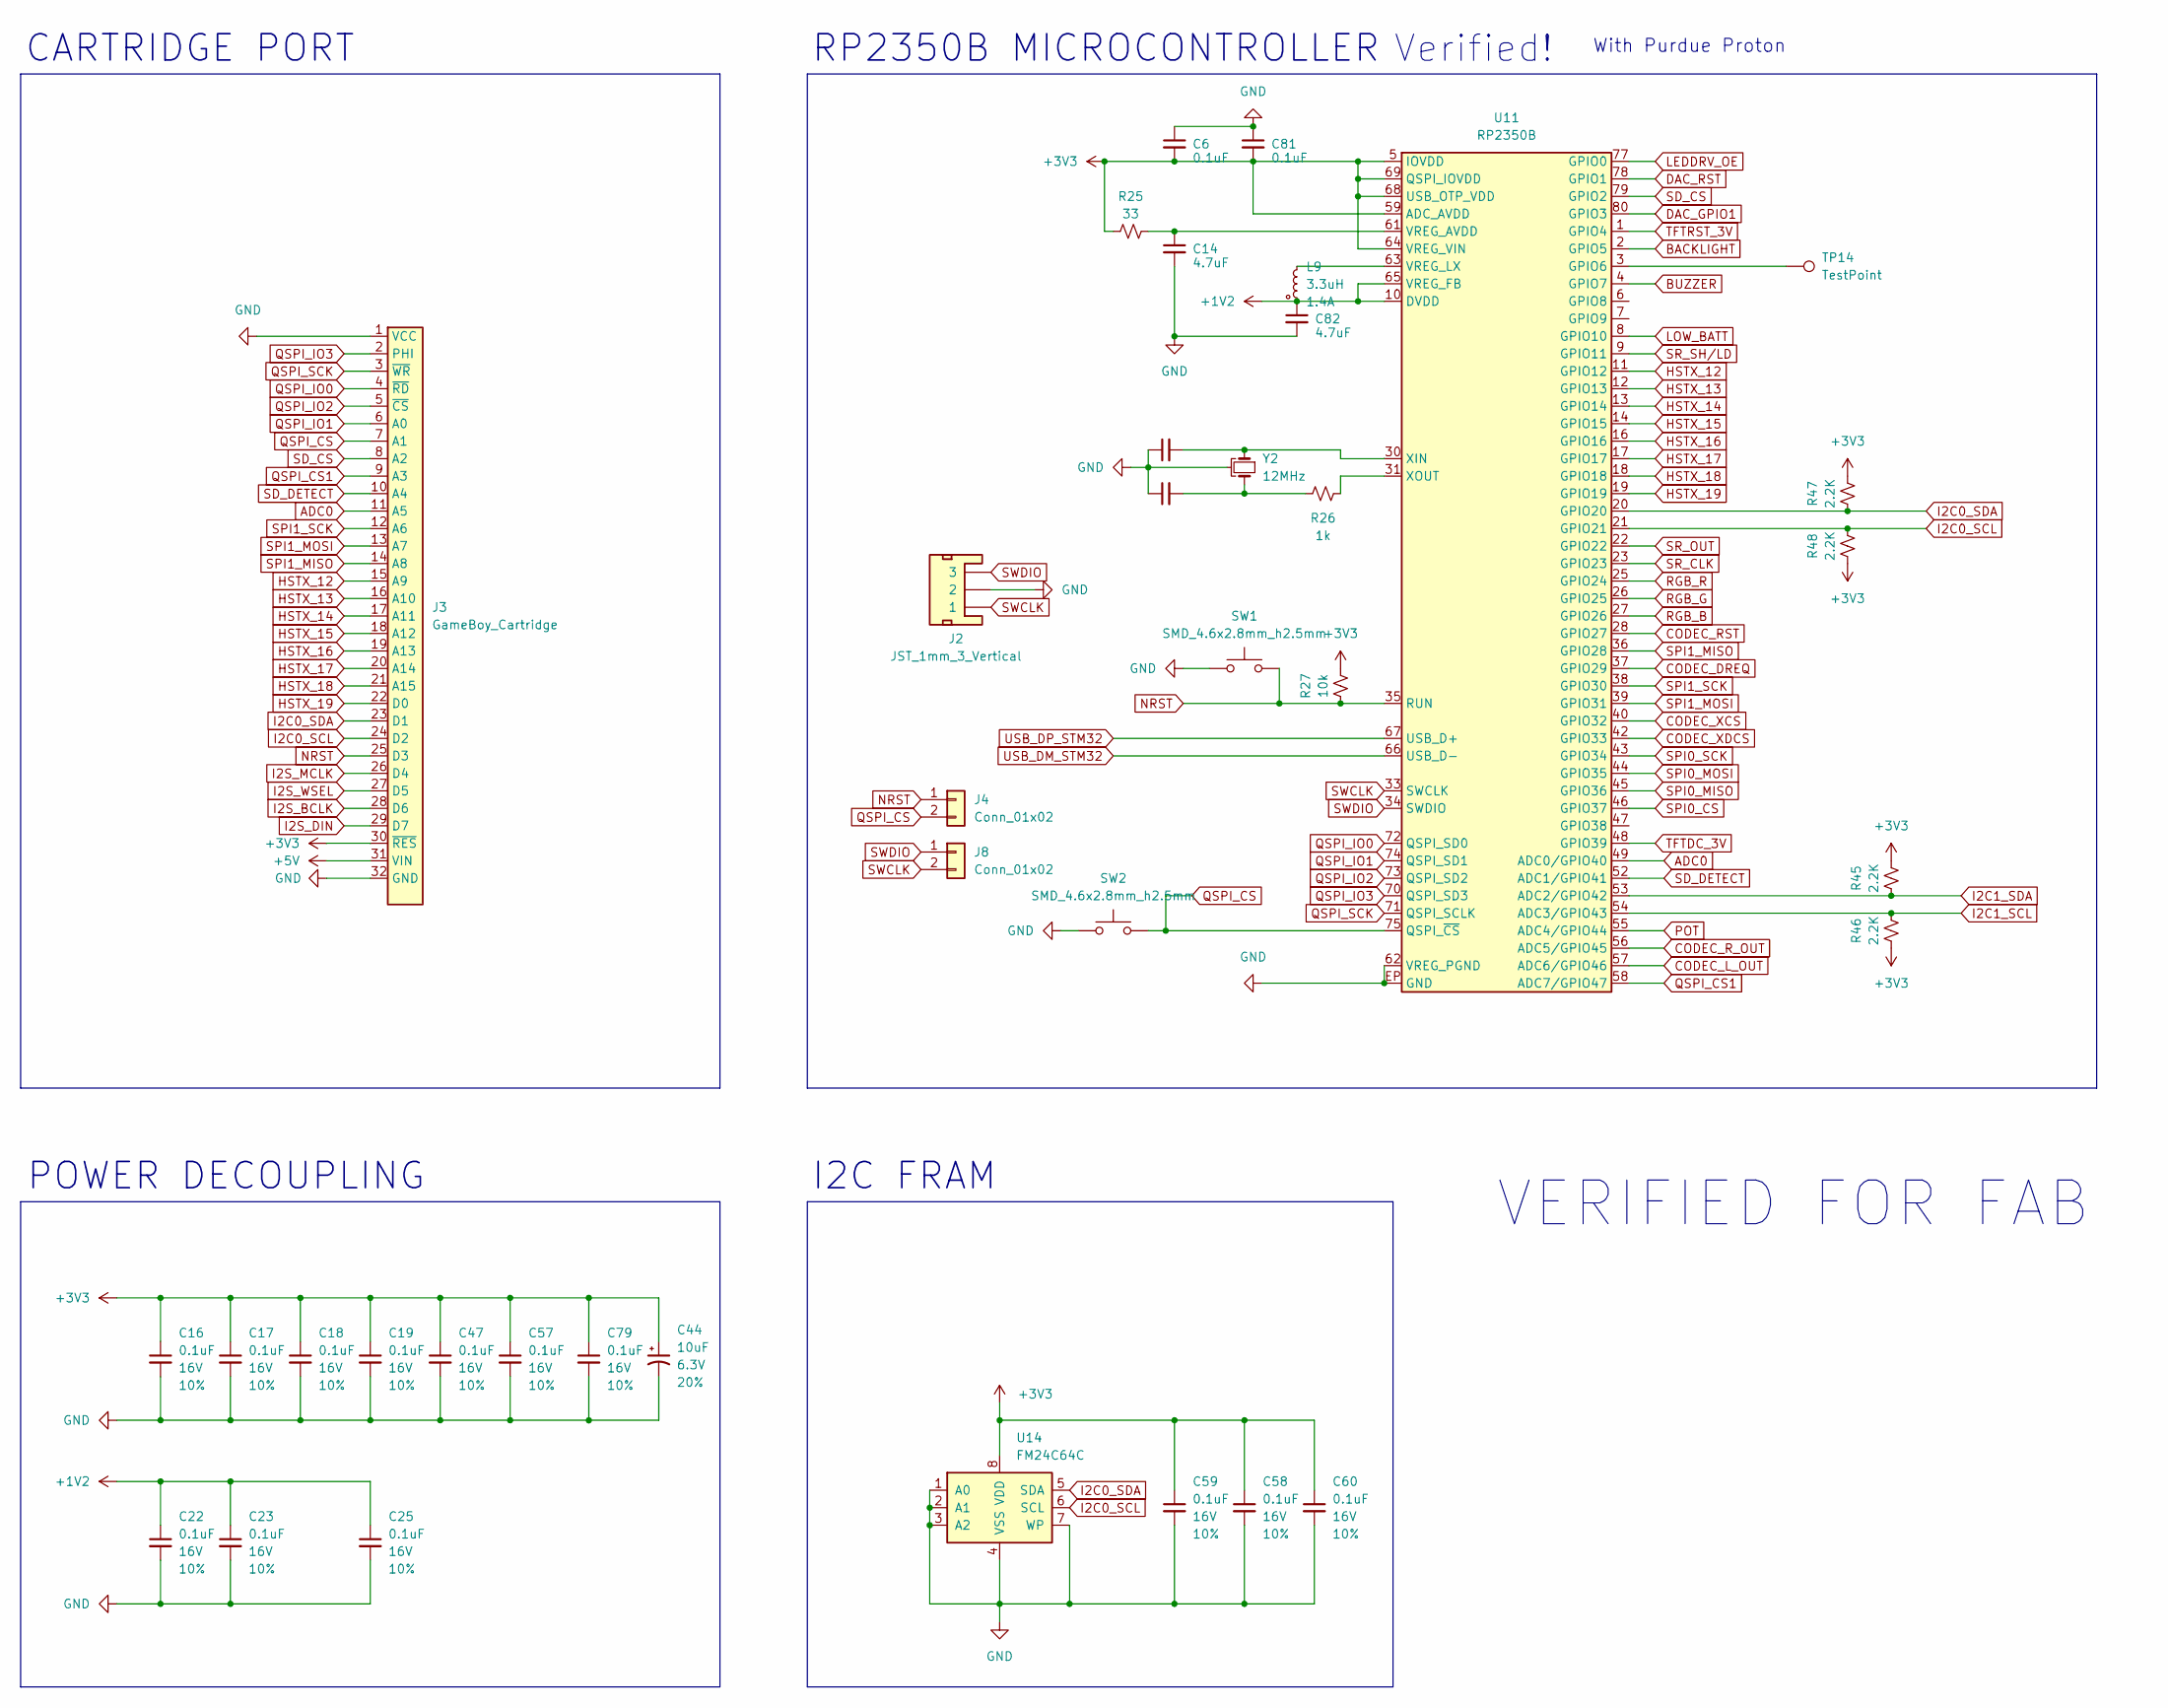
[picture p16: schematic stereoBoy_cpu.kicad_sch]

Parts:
C6: 0.1uF; C_0402_1005Metric
C14: 4.7uF; C_0402_1005Metric
C16, C17, C18, C19, C22, C23, C25, C47, C57, C58, C60, C79: 0.1uF; C_0402_1005Metric; Voltage 16V; Tolerance 10%
C20, C21: 15pF; C_0402_1005Metric; Voltage 50V; Tolerance 5%
C44: 10uF; CP_Elec_6.3x4.5; Voltage 6.3V; Tolerance 20%
C59: 0.1uF; C_0805_2012Metric; Voltage 16V; Tolerance 10%
C81: 0.1uF; WAi_0402_1005Metric
C82: 4.7uF; WAi_0402_1005Metric
J2: JST_1mm_3_Vertical; JST_1x03_P1.0mm_Horizontal_SMD
J3: GameBoy_Cartridge; MGB-CART-CONN
J4, J8: Conn_01x02; 1x02_P2.54mm
L9: 3.3uH; L_Cenker_CKCS201610
R25: 33; R_0402_1005Metric
R26: 1k; R_0402_1005Metric
R27: 10k; R_0603_1608Metric
R45, R46, R47, R48: 2.2K; R_0402_1005Metric
SW1, SW2: SMD_4.6x2.8mm_h2.5mm; Push_SMD_4.6x2.8mm_h2.5mm
TP14: TestPoint; TestPoint_Pad_D1.0mm
U11: RP2350B; QFN-80-1EP_10x10mm_P0.4mm_EP3.4x3.4mm
U14: FM24C64C; SOIC-8_3.9x4.9mm_P1.27mm
Y2: 12MHz; Crystal_SMD_3225-4Pin_3.2x2.5mm

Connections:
+1V2: C22.1, C23.1, C25.1, C82.1, L9.1, U11.10 (DVDD), U11.32 (DVDD), U11.51 (DVDD), U11.65 (VREG_FB)
+3V3: C6.2, C16.1, C17.1, C18.1, C19.1, C44.1, C47.1, C57.1, C58.1, C59.1, C60.1, C79.1, C81.2, J3.30 (~RES), R25.1, R27.2, R45.2, R46.1, R47.2, R48.1, U11.5 (IOVDD), U11.15 (IOVDD), U11.24 (IOVDD), U11.29 (IOVDD), U11.41 (IOVDD), U11.50 (IOVDD), U11.59 (ADC_AVDD), U11.60 (IOVDD), U11.64 (VREG_VIN), U11.68 (USB_OTP_VDD), U11.69 (QSPI_IOVDD), U11.76 (IOVDD), U14.8 (VDD); also elsewhere on the board
+5V: J3.31 (VIN); also elsewhere on the board
ADC0: J3.11 (A5), U11.49 (ADC0/GPIO40)
BACKLIGHT: U11.2 (GPIO5); also elsewhere on the board
BUZZER: U11.4 (GPIO7); also elsewhere on the board
CODEC_DREQ: U11.37 (GPIO29); also elsewhere on the board
CODEC_L_OUT: U11.57 (ADC6/GPIO46); also elsewhere on the board
CODEC_RST: U11.28 (GPIO27); also elsewhere on the board
CODEC_R_OUT: U11.56 (ADC5/GPIO45); also elsewhere on the board
CODEC_XCS: U11.40 (GPIO32); also elsewhere on the board
CODEC_XDCS: U11.42 (GPIO33); also elsewhere on the board
DAC_GPIO1: U11.80 (GPIO3); also elsewhere on the board
DAC_RST: U11.78 (GPIO1); also elsewhere on the board
GND: C6.1, C14.2, C16.2, C17.2, C18.2, C19.2, C20.1, C21.1, C22.2, C23.2, C25.2, C44.2, C47.2, C57.2, C58.2, C59.2, C60.2, C79.2, C81.1, C82.2, J2.2, J3.1 (VCC), J3.32 (GND), SW1.1, SW2.1, U11.62 (VREG_PGND), U11.EP (GND), U14.1 (A0), U14.2 (A1), U14.3 (A2), U14.4 (VSS), U14.7 (WP), Y2.2, Y2.4; also elsewhere on the board
HSTX_12: J3.15 (A9), U11.11 (GPIO12)
HSTX_13: J3.16 (A10), U11.12 (GPIO13)
HSTX_14: J3.17 (A11), U11.13 (GPIO14)
HSTX_15: J3.18 (A12), U11.14 (GPIO15)
HSTX_16: J3.19 (A13), U11.16 (GPIO16)
HSTX_17: J3.20 (A14), U11.17 (GPIO17)
HSTX_18: J3.21 (A15), U11.18 (GPIO18)
HSTX_19: J3.22 (D0), U11.19 (GPIO19)
I2C0_SCL: J3.24 (D2), R48.2, U11.21 (GPIO21), U14.6 (SCL); also elsewhere on the board
I2C0_SDA: J3.23 (D1), R47.1, U11.20 (GPIO20), U14.5 (SDA); also elsewhere on the board
I2C1_SCL: R46.2, U11.54 (ADC3/GPIO43); also elsewhere on the board
I2C1_SDA: R45.1, U11.53 (ADC2/GPIO42); also elsewhere on the board
I2S_BCLK: J3.28 (D6); also elsewhere on the board
I2S_DIN: J3.29 (D7); also elsewhere on the board
I2S_MCLK: J3.26 (D4); also elsewhere on the board
I2S_WSEL: J3.27 (D5); also elsewhere on the board
LEDDRV_OE: U11.77 (GPIO0); also elsewhere on the board
LOW_BATT: U11.8 (GPIO10); also elsewhere on the board
NRST: J3.25 (D3), J4.1, R27.1, SW1.2, U11.35 (RUN)
unnamed: C21.2, R26.1, Y2.3
unnamed: TP14.1, U11.3 (GPIO6)
unnamed: C14.1, R25.2, U11.61 (VREG_AVDD)
unnamed: L9.2, U11.63 (VREG_LX)
unnamed: C20.2, U11.30 (XIN), Y2.1
unnamed: R26.2, U11.31 (XOUT)
POT: U11.55 (ADC4/GPIO44); also elsewhere on the board
QSPI_CS: J3.7 (A1), J4.2, SW2.2, U11.75 (QSPI_~CS)
QSPI_CS1: J3.9 (A3), U11.58 (ADC7/GPIO47)
QSPI_IO0: J3.4 (~RD), U11.72 (QSPI_SD0)
QSPI_IO1: J3.6 (A0), U11.74 (QSPI_SD1)
QSPI_IO2: J3.5 (~CS), U11.73 (QSPI_SD2)
QSPI_IO3: J3.2 (PHI), U11.70 (QSPI_SD3)
QSPI_SCK: J3.3 (~WR), U11.71 (QSPI_SCLK)
RGB_B: U11.27 (GPIO26); also elsewhere on the board
RGB_G: U11.26 (GPIO25); also elsewhere on the board
RGB_R: U11.25 (GPIO24); also elsewhere on the board
SD_CS: J3.8 (A2), U11.79 (GPIO2)
SD_DETECT: J3.10 (A4), U11.52 (ADC1/GPIO41)
SPI0_CS: U11.46 (GPIO37); also elsewhere on the board
SPI0_MISO: U11.45 (GPIO36); also elsewhere on the board
SPI0_MOSI: U11.44 (GPIO35); also elsewhere on the board
SPI0_SCK: U11.43 (GPIO34); also elsewhere on the board
SPI1_MISO: J3.14 (A8), U11.36 (GPIO28); also elsewhere on the board
SPI1_MOSI: J3.13 (A7), U11.39 (GPIO31); also elsewhere on the board
SPI1_SCK: J3.12 (A6), U11.38 (GPIO30); also elsewhere on the board
SR_CLK: U11.23 (GPIO23); also elsewhere on the board
SR_OUT: U11.22 (GPIO22); also elsewhere on the board
SR_SH/LD: U11.9 (GPIO11); also elsewhere on the board
SWCLK: J2.1, J8.2, U11.33 (SWCLK)
SWDIO: J2.3, J8.1, U11.34 (SWDIO)
TFTDC_3V: U11.48 (GPIO39); also elsewhere on the board
TFTRST_3V: U11.1 (GPIO4); also elsewhere on the board
USB_DM_STM32: U11.66 (USB_D-); also elsewhere on the board
USB_DP_STM32: U11.67 (USB_D+); also elsewhere on the board

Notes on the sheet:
VERIFIED FOR FAB
With Purdue Proton
I2C FRAM
POWER DECOUPLING
Verified!
CARTRIDGE PORT
RP2350B MICROCONTROLLER

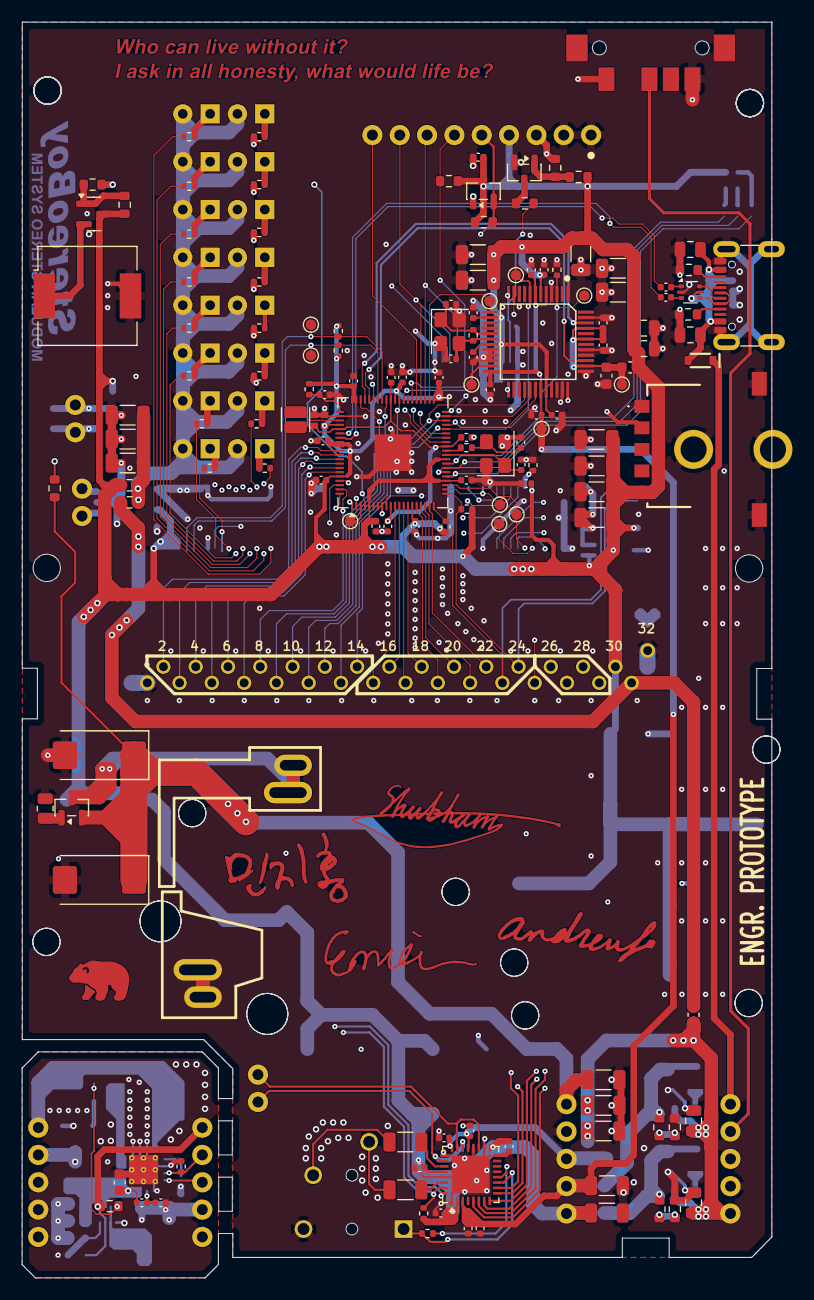
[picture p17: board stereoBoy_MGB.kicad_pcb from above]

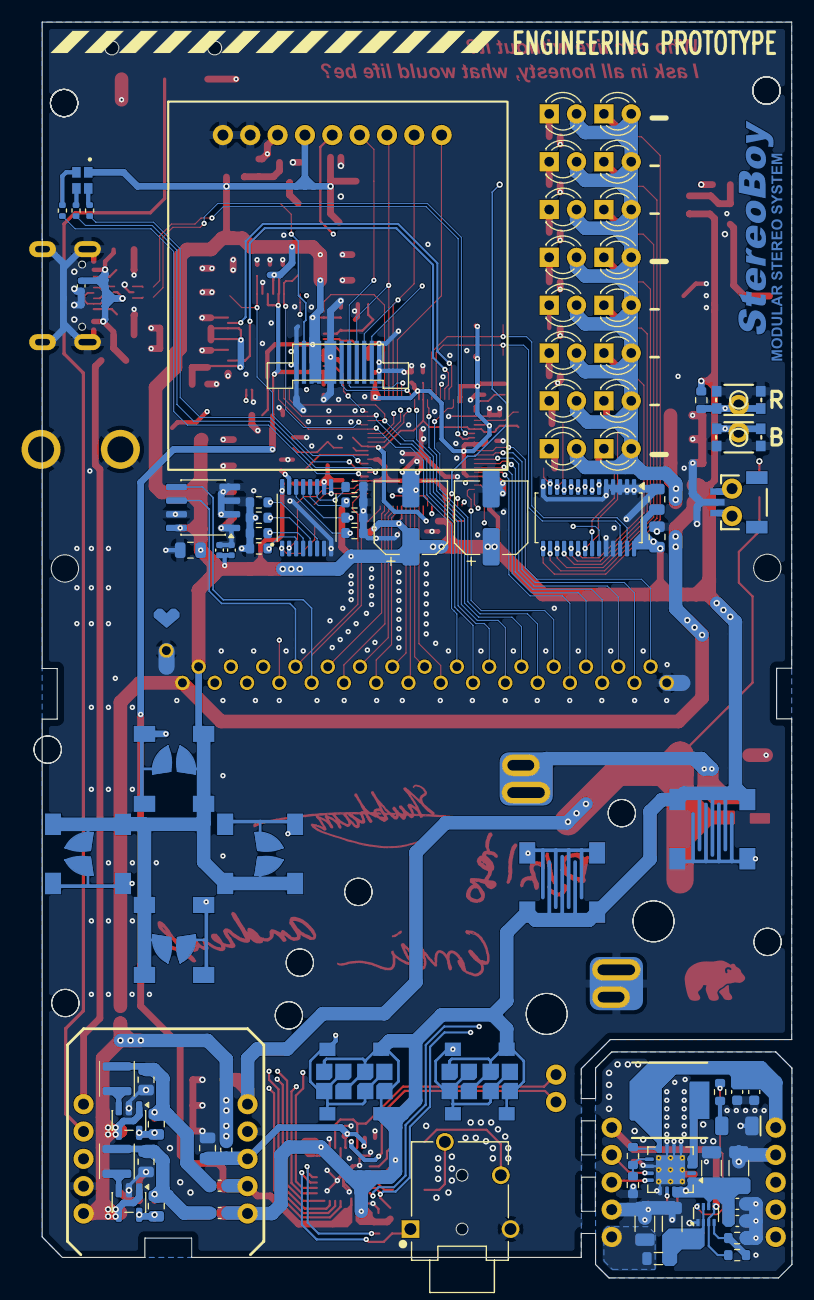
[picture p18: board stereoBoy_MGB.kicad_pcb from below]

Board: 4 copper layers, 69.7 x 116.7 mm, 249 parts (84 on the bottom side), 165 nets.

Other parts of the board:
UNK_HOLE_0: dummyfp0
UNK_HOLE_1: dummyfp1
UNK_HOLE_4: dummyfp4
UNK_HOLE_5: dummyfp5
UNK_HOLE_6: dummyfp6
UNK_HOLE_7: dummyfp7
UNK_HOLE_8: dummyfp8
UNK_HOLE_9: dummyfp9
UNK_HOLE_10: dummyfp10
UNK_HOLE_11: dummyfp11
UNK_HOLE_12: dummyfp12

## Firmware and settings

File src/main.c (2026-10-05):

#include "lib/sb_util/global_vars.h"

#include "lib/sb_util/sb_util.h"
#include "lib/buttons/buttons.h"
#include "lib/pot/pot.h"

#include "pico/stdlib.h"
#include <stdint.h>
#include "stdio.h"
#include "ff.h"
#include "hardware/vreg.h"
#include "hardware/clocks.h"
#include "lib/sb_util/interface.h"
#include "lib/fram/fram.h"

// SPI1 configuration for codec & sd card
#define PIN_SCK  30
#define PIN_MOSI 28
#define PIN_MISO 31
#define PIN_CS   32

// Codec control signals
#define PIN_DCS  33
#define PIN_DREQ 29
#define PIN_RST  27

// I2C0 for DAC
#define PIN_I2C0_SCL 21
#define PIN_I2C0_SDA 20

uint16_t song_choice = 0;
uint16_t album_choice = 0;
uint16_t artist_choice = 0;

uint16_t last_played_track_idx = 0;
uint16_t last_played_album_idx = 0;
uint16_t last_played_artist_idx = 0;

vs1053_t player = {
    .spi = spi1,
    .cs = PIN_CS,
    .dcs = PIN_DCS,
    .dreq = PIN_DREQ,
    .rst = PIN_RST
};

st7789_t display = {
    .spi      = spi0,
    .gpio_din = 35,
    .gpio_clk = 34,
    .gpio_cs  = 37,
    .gpio_dc  = 39,
    .gpio_rst = 4,
    .gpio_bl  = 5,
};

folder_info_t folders[MAX_FOLDERS];

// file that contains all tracks' metadata
// VERY IMPORTANT
FIL tracks_cache_file;

char folder_names[20][64];
int folder_file_counts[20];

int exitCode = 0;

int main() {
    // set_visualizer(6);
    // Lower RP2350 core voltage to 1V
    // P = V^2 * f, so 0.1V drop results in quadratic change
    // Before: 1.1 ^ 2 * 150 = 181.5
    // Now: 1.0 ^ 2 * 150 = 150
    vreg_set_voltage(VREG_VOLTAGE_1_00);

    stdio_init_all();

    sb_hw_init(&player, &display);
    
    // Boot-up banner

    printf("\033c"); // clear screen

    printf(R"(
   _____ __                       ____             
  / ___// /____  ________  ____  / __ )____  __  __ 
  \__ \/ __/ _ \/ ___/ _ \/ __ \/ __  / __ \/ / / /
 ___/ / /_/  __/ /  /  __/ /_/ / /_/ / /_/ / /_/ / 
/____/\__/\___/_/   \___/\____/_____/\____/\__, /  
   MODULAR SUPER HI-FI STEREO SYSTEM      /____/
   ENGINEERING PROTOTYPE UNIT 001)");
    printf("\r\n\r\n");

    // sleep_ms(750); // pause for dramatic effect

    // printf("Starting Folder Scan...\n");

    // uint8_t total_folders = sb_scan_folders(folders, 20);
    // printf("--- Found %d Folders ---\n", total_folders);
    // for (int i = 0; i < total_folders; i++) {
    //     printf("[%02d] %-16s (%d songs)\n", 
    //             i, 
    //             folders[i].foldername, 
    //             folders[i].num_tracks);
    // }

    dprint("Starting Track Scan");

    // parse .sbc cache files and load library metadata
    sb_load_library();
    if (sb_load_tracks_cache(&tracks_cache_file) != FR_OK) {
        while(1) {
            printf("What the fuck just happened\n");
            sleep_ms(1000);
        }
    }

    last_played_track_holder = current_track_holder; 
    last_played_track = &last_played_track_holder;

    // uint32_t last_played_pos = 0;
    // read last played song and fetch its metadata
    int status = fram_read(i2c0, 0x0000, (uint8_t*)&last_played_track_idx, sizeof(last_played_track_idx));
    if (status > 0 && last_played_track_idx < track_count) {
        // song_choice = last_played_track_idx;
        printf("[F-RAM] Loaded last track: %d\n", song_choice);
    } else {
        printf("[F-RAM Warning] Invalid read (%d) or bus failure. Defaulting to track 0.\n", last_played_track_idx);
        song_choice = 0; // Fallback to track 0 safely
    }

    if (!sb_get_track_window_fast(&tracks_cache_file, last_played_track_idx, last_played_track, track_window)) {
        printf("Error reading track metadata from cache table!\n");
    }

    printf("%d Artists\n", artist_count);
    printf("%d Albums\n", album_count);
    printf("%d Tracks\n", track_count);

    menu_choice = 1;
    uint16_t selected = 65535;

    while (1) {
        exitCode = 0;
        menu_choice = 1;
        selected = 65535;
        
        set_visualizer(7);
        while(selected == 65535) {
            // TODO: add left and right for fast scrolling
            switch (buttons_get_action()) {
                case BTN_D:
                    menu_choice = (menu_choice + 1);
                    break;
                case BTN_U:
                    menu_choice = (menu_choice - 1);
                    break;
                case BTN_A:
                    selected = 1;   
                    printf("Main: Poo cum fart shit pee\n");
                    break;
                default:
                    break;
            }
            if (menu_choice < 1) {
                menu_choice = 1;
            } else if (menu_choice > 7) {
                menu_choice = 7;
            }
            sleep_ms(50);
        }

        switch (menu_choice) {
            // Artists -> Albums -> Tracks
            case 1: {
                selected = 0;
                uint16_t start_album = browse_artists(&exitCode);
                if (start_album == 65535) {
                    break;
                }
                album_choice = start_album;

                selected = 0;
                uint16_t start_track = browse_albums(&exitCode);
                if (start_track == 65535) {
                    break;
                }
                song_choice = start_track;

                int result = 0;
                while (result != 65535) {
                    result = browse_tracks(&exitCode);
                }
                break;
            }

            // Albums -> Tracks
            case 2: {
                selected = 0;
                uint16_t start_track = browse_albums(&exitCode);
                if (start_track == 65535) {
                    break;
                }
                song_choice = start_track;

                int result = 0;
                while (result != 65535) {
                    result = browse_tracks(&exitCode);
                }
                break;
            }

            // Tracks (Direct Browse)
            case 3: {
                int result = 0;
                while (result != 65535) {
                    result = browse_tracks(&exitCode);
                }
                break;
            }
            // Last Played
            case 4: {
                song_choice = last_played_track_idx;
                album_choice = last_played_album_idx;
                artist_choice = last_played_artist_idx;
                exitCode = -1; // if exitCode != 0, browse_tracks skips the selection menu and goes straight to jukebox
                int result = 0;
                while (result != 65535) {
                    result = browse_tracks(&exitCode);
                }
                break;
            }
            // Shuffle All
            case 5:
                break;
            
            default:
                break;
        }
    }
}

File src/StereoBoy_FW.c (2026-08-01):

#include "lib/sb_util/global_vars.h"

#include "lib/sb_util/sb_util.h"
#include "lib/buttons/buttons.h"
#include "lib/pot/pot.h"

#include "pico/stdlib.h"
#include "stdio.h"
#include "ff.h"
#include "hardware/vreg.h"

// SPI1 configuration for codec & sd card
#define PIN_SCK  30
#define PIN_MOSI 28
#define PIN_MISO 31
#define PIN_CS   32

// Codec control signals
#define PIN_DCS  33
#define PIN_DREQ 29
#define PIN_RST  27

// I2C0 for DAC
#define PIN_I2C0_SCL 21
#define PIN_I2C0_SDA 20

vs1053_t player = {
    .spi = spi1,
    .cs = PIN_CS,
    .dcs = PIN_DCS,
    .dreq = PIN_DREQ,
    .rst = PIN_RST
};

struct st7789_t display = {
    .spi      = spi0,
    .gpio_din = 35,
    .gpio_clk = 34,
    .gpio_cs  = 37,
    .gpio_dc  = 39,
    .gpio_rst = 4,
    .gpio_bl  = 5,
};


#define LCD_WIDTH  240
#define LCD_HEIGHT 240

folder_info_t folders[MAX_FOLDERS];

track_info_t *current_track = NULL;
track_info_t current_track_holder;

// file that contains all tracks' metadata
// VERY IMPORTANT
FIL tracks_cache_file;

char folder_names[20][64];
int folder_file_counts[20];

uint16_t song_choice = 0;
uint16_t prev_choice = 0;
uint8_t selected = 0;

int temp_visualizer = 6;
int exitCode = 0;

int browse_tracks() {
    // read_lwbt();
    temp_visualizer = (visualizer == 7) ? 1 : visualizer;
    //Return to main menu with list selection:
    if (exitCode == 0) {
        // pca9685_all_off(&vu_meter);
        selected = false;
        set_visualizer(6);
        printf("\r\nSong %d/%d: ", song_choice+1, track_count);
        prev_choice = song_choice;
        while (selected == false) {
            uint8_t pressed = buttons_get_just_pressed();
            if (pressed > 0){
                if (pressed & BTN_D)      song_choice = (song_choice + 1) % track_count;
                if (pressed & BTN_U)      song_choice = (song_choice - 1 + track_count) % track_count; //added roll-over
                    // shift songs down by one and insert new song on top
                if (pressed & BTN_R)      song_choice = (song_choice + 10) % track_count;
                if (pressed & BTN_L)      song_choice = (song_choice - 10 + track_count) % track_count;
                if (pressed & BTN_B) {
                    return 100;
                }
                if (pressed & BTN_A) {
                    selected = true;   
                    printf("Poo cum fart shit pee\n");
                }       
                sb_get_track_window_fast(&tracks_cache_file, song_choice, current_track, track_window);
            }
            if (prev_choice != song_choice){
                printf("\r\nSong %d/%d: ", song_choice+1, track_count);
                prev_choice = song_choice;
            }
            
            sleep_ms(10);
        }
    }

    if (!sb_get_track_window_fast(&tracks_cache_file, song_choice, current_track, track_window)) {
        printf("Error reading track metadata from cache table!\n");
    }

    get_mp3_metadata(current_track->filename, current_track);

    printf("\r\n\rNOW PLAYING:\r\n");
    printf("  Title : %s\r\n", current_track->title);
    printf("  Artist: %s\r\n", current_track->artist);
    printf("  Album : %s\r\n", current_track->album);
    printf("  Bitrate : %d Kbps\r\n", current_track->bitrate);
    printf("  Sample rate : %d Hz\r\n", current_track->samplespeed);
    printf("  Channels : %s\r\n", current_track->channels == 1 ? "Mono" : "Stereo");
    printf("  Header: %X\r\n", current_track->header);
    printf("  Start: %X\r\n", current_track->audio_start);
    printf("  Start: %X\r\n", current_track->audio_end);

    set_visualizer(temp_visualizer);

    // Pass it to the playback loop
    exitCode = jukebox(&player, current_track, &display);

    // play next song
    if (exitCode == 1){
        song_choice = (song_choice + 1) % track_count;
        printf("\r\n Next song!\r\n");
        dprint("Next song!");
    }
    // play previous song
    if (exitCode == 2){
        song_choice = (song_choice - 1 + track_count) % track_count;
        dprint("Prev Song!");
        printf("\r\nPrev Song!\r\n");
    }
    // play selected song in menu (visualizer 6)
    if (exitCode == 3){
        dprint("Playing picked Song!");
        printf("\r\nPlaying picked Song!\r\n");
    }

    return 0;
}

int main() {
    set_visualizer(6);
    // Lower RP2350 core voltage to 1V
    // P = V^2 * f, so 0.1V drop results in quadratic change
    // Before: 1.1 ^ 2 * 150 = 181.5
    // Now: 1.0 ^ 2 * 150 = 150
    vreg_set_voltage(VREG_VOLTAGE_1_00);

    stdio_init_all();

    sb_hw_init(&player, &display);
    
    // Boot-up banner

    // printf("\033c"); // clear screen

    printf(R"(
   _____ __                       ____             
  / ___// /____  ________  ____  / __ )____  __  __ 
  \__ \/ __/ _ \/ ___/ _ \/ __ \/ __  / __ \/ / / /
 ___/ / /_/  __/ /  /  __/ /_/ / /_/ / /_/ / /_/ / 
/____/\__/\___/_/   \___/\____/_____/\____/\__, /  
   MODULAR SUPER HI-FI STEREO SYSTEM      /____/
   ENGINEERING PROTOTYPE UNIT 001)");
    printf("\r\n\r\n");

    // sleep_ms(750); // pause for dramatic effect

    // printf("Starting Folder Scan...\n");

    // uint8_t total_folders = sb_scan_folders(folders, 20);
    // printf("--- Found %d Folders ---\n", total_folders);
    // for (int i = 0; i < total_folders; i++) {
    //     printf("[%02d] %-16s (%d songs)\n", 
    //             i, 
    //             folders[i].foldername, 
    //             folders[i].num_tracks);
    // }

    dprint("Starting Track Scan");

    // Load your main relational pointers into RAM first
    sb_load_library();
    if (sb_load_tracks_cache(&tracks_cache_file) != FR_OK) {
        while(1) {
            printf("What the fuck just happened\n");
            sleep_ms(1000);
        }
    }

    printf("%d Artists\n", artist_count);
    printf("%d Albums\n", album_count);
    printf("%d Tracks\n", track_count);

    prev_choice = 0;
    song_choice = 1;
    selected = 100;

    current_track = &current_track_holder;
    if (!sb_get_track_window_fast(&tracks_cache_file, song_choice, current_track, track_window)) {
        printf("Error reading track metadata from cache table!\n");
    }
    while (1) {
        prev_choice = 0;
        song_choice = 1;
        selected = 100;
        
        set_visualizer(7);
        while(selected == 100) {
            uint8_t pressed = buttons_get_just_pressed();
            if (pressed > 0){
                if (pressed & BTN_D)      song_choice = (song_choice + 1);
                if (pressed & BTN_U)      song_choice = (song_choice - 1);
                if (pressed & BTN_A){
                    selected = 1;   
                    printf("Poo cum fart shit pee\n");
                }
                if (song_choice < 1) {
                    song_choice = 1;
                } else if (song_choice > 7) {
                    song_choice = 7;
                }
            }
            sleep_ms(50);
        }
        
        selected = 0;
        song_choice = 0;
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

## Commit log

2026-05-09 starting work on optimizing boot time. Got raw track scan working.
2026-05-09 much faster boot times but still too slow. implemented fast MD extraction as a band-aid
    [StereoBoy_FW.c]
2026-05-13 minor volume fix - moved potVal reading from addIcons to core1_entry
    [StereoBoy_FW.c]
2026-06-21 culling dependencies for on-board image decoding
2026-06-27 minor sd card fixes
    [hw_config.c]
2026-06-28 fixed SD card mount but not sure
    [StereoBoy_FW.c, hw_config.c]
2026-07-02 working on slashing RAM use with cached LUTs. Core 0 mostly works but Core 1 stuck
    [StereoBoy_FW.c]
2026-07-02 not sure what I did but cut ram usage by over 20%
2026-07-02 annoying audio glitch fixed on first playback, but still shitshow
    [StereoBoy_FW.c]
2026-07-02 minor fixes but still dogshit
    [StereoBoy_FW.c]
2026-07-03 about 3s boot time, 41% mem used, FS-based library mostly working. Core 1 still stuck
    [StereoBoy_FW.c]
2026-07-05 Implemented fully cache-based MD fetching, POD no longer necessary
    [StereoBoy_FW.c]
2026-07-05 Fully FOD now, no more POD. Core 1 is pretty buggy
    [StereoBoy_FW.c]
2026-07-05 fixed ripMD to organize tracks by disc and track number
2026-07-06 sdio prototype working
2026-07-07 fixed track count debug prints
    [StereoBoy_FW.c]
2026-07-12 fixed track window but lots of optimization needed
    [StereoBoy_FW.c]
2026-07-12 added track cache now stays open, plus VU meter fixes
    [StereoBoy_FW.c]
2026-07-12 fixed track window parse/render but really gotta fix it more
2026-08-01 working on fixing menu hardfault heisenbug
    [StereoBoy_FW.c]
2026-08-01 fixed track window hardfault heisenbug. Converted window fetcher to always open
    [StereoBoy_FW.c]
2026-08-01 removed kicad stuff
    [stereoBoy_MGB.kicad_pcb]
2026-08-06 gotta fix kinks in visualizer setting of main.c
    [main.c]
2026-08-09 fixed minor bug with album menu
    [main.c]
2026-08-12 fixed small menu bug
    [main.c]
2026-09-19 rgb led now actually does something (ff/rew/pause indicator in jukebox)
2026-09-25 working on rewriting button logic
2026-09-25 still working on simplifying button logic
2026-09-30 added kicad source files
    [AA Battery Cover V4.stl, AA Battery Pocket Rear V7.stl, OEM CURVE FRONT Revised.stl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]
2026-10-04 implemented double-buffering track metadata for currently playing vs currently selected
2026-10-05 drill-up now possible for artists-albums-tracks
